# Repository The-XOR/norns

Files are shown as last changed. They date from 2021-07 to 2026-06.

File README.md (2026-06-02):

# Trapanaorecchie
Versione vergognosa e barbona dello stilosissimo monome norns.

Funzionante e compatibile al 100%, con vere porte MIDI e un uscita cuffia che non esitiamo a definire "molto utile".

L'aspetto l'e' quel che l'e', ma fatto com'e' con tutti pezzi di recupero, di piu' non si poteva fare.

## quick reference

```
git clone https://github.com/The-XOR/norns.git
cd norns
git submodule update --init --recursive
./waf configure --release
./waf build --release
```

(NB: the `--release` flag creates builds specifically for armv8/cortex-a53 instruction set, meaning optimized for rpi3 and compatible with rpi4. It also enables aggressive compiler optimizations. Omit flag if you need debug symbols or to build for a different architecture. It does need to supplied to both configuration and build steps.)

## documentation
- [user docs](https://monome.org/docs/norns)
- [API docs](https://monome.org/docs/norns/api)
- [building and execution](readme-setup.md)
- [discussion and help](https://llllllll.co)

## related
### supporting repositories
- [maiden](https://github.com/The-XOR/maiden/) | editing interface
- [softcut](https://github.com/monome/softcut-lib) | sample-cutting editor part of `matron`

### tools
- [norns disk image](https://github.com/The-XOR/norns-image) | raspbian-based disk image
- [monome linux kernel](https://github.com/monome/linux/) | custom, monome-flavored linux kernel
- [DIY shield instructions](https://github.com/monome/norns-shield) | the DIY open-source hardware variant

## acknowledgments

`matron` (control system) and `crone` (audio system) were created by [@catfact](https://github.com/catfact). `maiden` (editor) was created by [@ngwese](https://github.com/ngwese). Each grew with contributions from [@artfwo](https://github.com/artfwo), [@antonhornquist](https://github.com/antonhornquist), [@simonvanderveldt](https://github.com/simonvanderveldt),[@ranch-verdin](https://github.com/ranch-verdin), [@pq](https://github.com/pq), [@markwheeler](https://github.com/markwheeler), [@csboling](https://github.com/csboling) and many others.

norns was initiated by [@tehn](https://github.com/tehn) (monome).

## la fotogalleria...

... che lo mostra in tutto il suo splendore. Il colore e' quello pentecostale, a ricordare le ristrettezze economiche che hanno dato i natali.

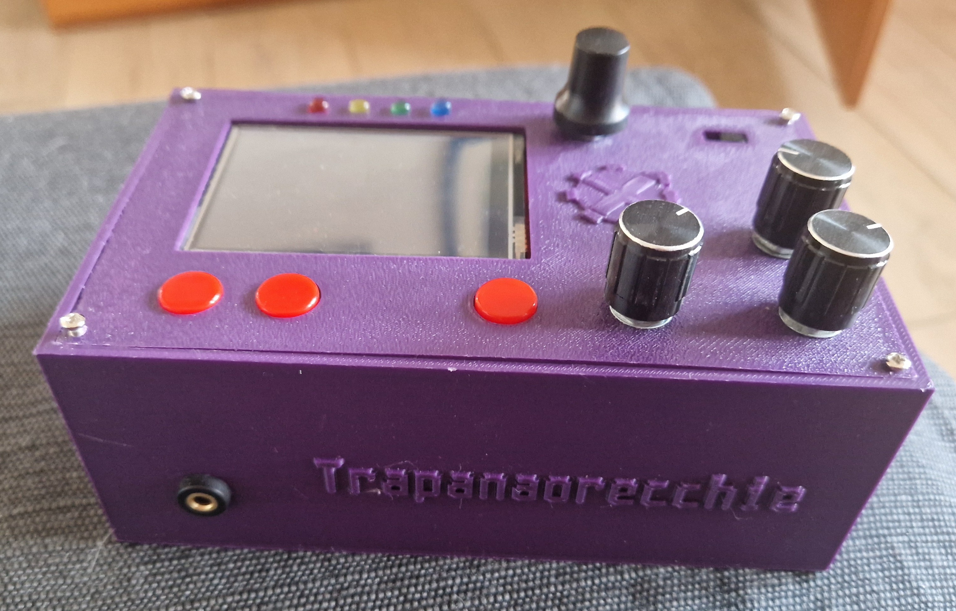
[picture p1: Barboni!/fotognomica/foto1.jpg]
e uno


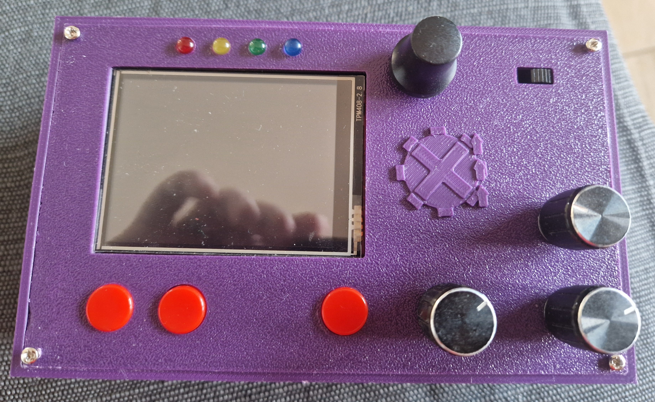
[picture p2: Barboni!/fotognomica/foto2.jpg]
e due


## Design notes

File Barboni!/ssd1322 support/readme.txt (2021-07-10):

/home/pi/linux/drivers/staging/fbtft:
1. KCONFIG: inserire il contenuto del file kconfig.merge
2. copiare in questa directory il file fb_ssd1322.c

menuconfig (kernel build):
[D]evice Drivers --> [S]taging Drivers --> [S]upport for small TFT LCD display modules -->
<M> SSD1322 driver

File makefile:
aggiungere
obj-$(CONFIG_FB_TFT_SSD1322)     += fb_ssd1322.o

file modules.order:
aggiungere
drivers/staging/fbtft/fb_ssd1322.ko

ricompilare lo kernel

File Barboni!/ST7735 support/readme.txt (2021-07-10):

Basandosi sul file "dts list", il display ST7735r viene attivato col comando:

dtoverlay=adafruit18,reset_pin=6,dc_pin=5,rotate=270

NOTA:
il piedino DC corrisponde a RS nel pdf allegato.
L'utilizzo del termine "PIN" è improprio, in realtà è il numero di GPIO.

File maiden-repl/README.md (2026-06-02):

maiden-repl
===========

the `maiden-repl` command is a terminal based alternative to the `matron`
and `supercollider` (sc/crone) REPLs provided in the web based `maiden` editor. this
command can be used independently of, or concurrently with, the web based editor. any
REPL output will appear in all connected sessions but REPL input commands and command
history.

usage
-----

`maiden-repl <matron_socket> <crone_socket>`

the default values for `matron_socket` and `crone_socket` are
`ws://localhost:5555/` and `ws://localhost:5556/` respectively which are
appropriate if `maiden-repl` is being run directly on `norns` (via ssh or serial
connection).

if running `maiden-repl` from another host insert the appropriate host name (or
IP address) for
your device such as:

```
maiden-repl ws://norns.local:5555 ws://norns.local:5556
```

building
--------

`maiden-repl` is known to build on:
* monome norns, norns shield os images
* linux (debian buster)
* macOS (13.1 Ventura)

when building directly on a norns device `maiden-repl` should be built by
default as part of the `waf` based build system for the full norns software
stack (matron, crone, etc.)

when building on linux or macOS the a secondary `cmake` based build sytem allows
for building the command independently of the full norns stack. the `cmake`
system is very rudimentary.

on linux manually install the following dependencies:
```
sudo apt-get install cmake libncursesw5-dev libreadline-dev libnanomsg-dev
```

on macOS ensure the XCode developer commandline tools are installed then manually install the following (via Homebrew):
```
brew install cmake readline nanomsg
```

from there on either linux or macOS:
```
git clone https://github.com/The-XOR/norns.git
cd norns/maiden-repl
mkdir build
cd build
cmake ..
make
```

the resulting `maiden-repl` command in the build directory can be copied out and
placed in a directory which is on one's `PATH`.

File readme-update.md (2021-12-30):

# norns update procedure

## update information and bundling

upon entering the `SYSTEM > UPDATE` menu the update folder `~/update/` is scanned for files
matching the `norns*.tgz` pattern. any attached USB disk has its root folder checked as well.
if present the following process happens:

- file is extracted
- md5 check
- if success, extract data to folder
- cleanup (delete archives and md5)

updates are stored as folders.\*

when an update is "executed" via the menu, the application runs `update.sh`
within the selected update's folder and then updates `version.txt` which is
also stored in `~/update`.

\* there is no reason to keep the update folders, they should be deleted after being run. also, an
update's version number should be checked against the current version, to prevent backwards
updating (which would likely only break a bunch of functionality).

## anatomy of an update .tgz

update versions tracked by date YYMMDD.

ie `norns180401.tgz`

inside this archive is:

`180401.tgz`
`180401.md5`

the md5 validates the tgz. if passed, `180401.tgz` is extracted to `180401/`.

inside `180401/` is `update.sh`, `version.txt`, and the payload.

`update.sh` copies included files to the correct locations (and does whatever
else needs to be done).

`version.txt` simply contains the version (ie `180401`) and is copied to `~/update`
(which is later read by matron).

files relevant to matron, crone, or maiden should be kept in respective
subfolders in the archive.

## preparation of an update

generating an update is straightforward. make a YYMMDD folder, put all the
files in there with a correct `update.sh`.

```
tar czvf YYMMDD.tgz YYMMDD
md5sum YYMMDD.tgz > YYMMDD.md5
tar czvf nornsYYMMDD.tgz YYMMDD.*
```

## delivery

presently update files are copied to `~/update` via the `SYSTEM > UPDATE` menu, which checks the remote github release against the current version.

it's possible to manually install an update by copying the update file to `~/update`, extracting it, and running `update.sh` directly.

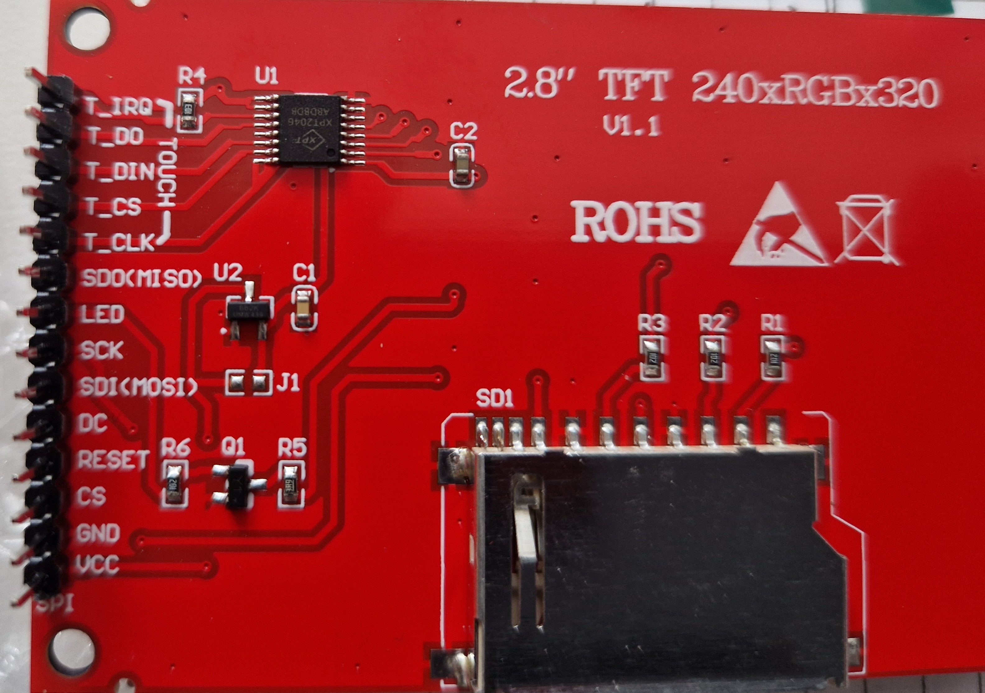
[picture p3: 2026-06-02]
Barboni!/Schema elettrificato/pinout display.jpg

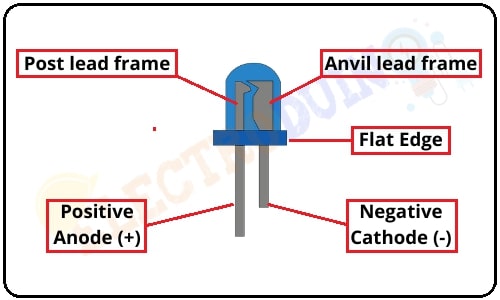
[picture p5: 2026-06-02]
Barboni!/Schema elettrificato/LED-or-Light-Emitting-Diode-Pinout.jpg

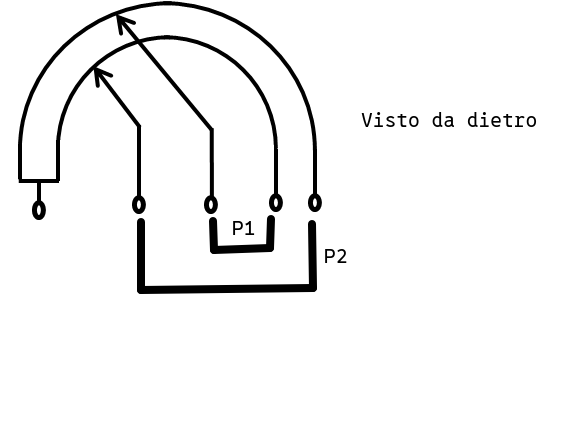
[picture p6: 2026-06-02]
Barboni!/Schema elettrificato/potenziometro a 5 pin.png

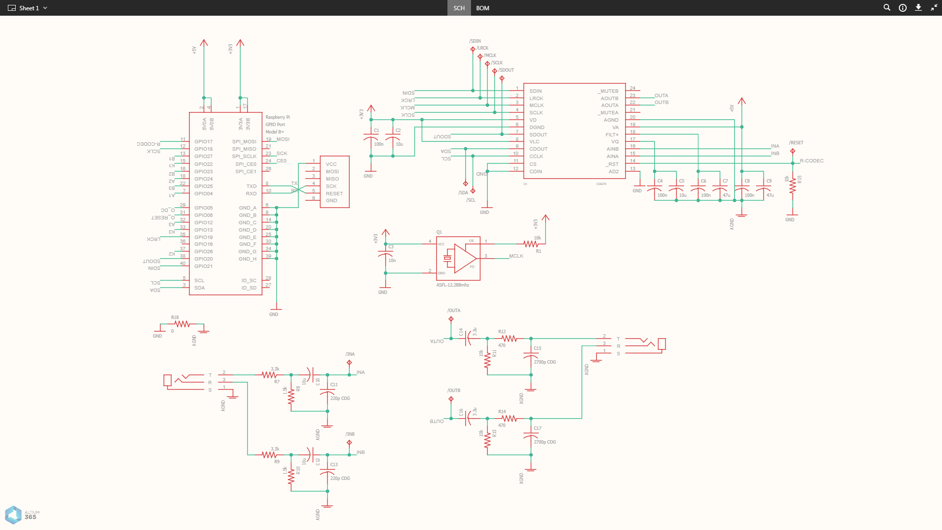
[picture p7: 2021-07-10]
Barboni!/norns-1.png

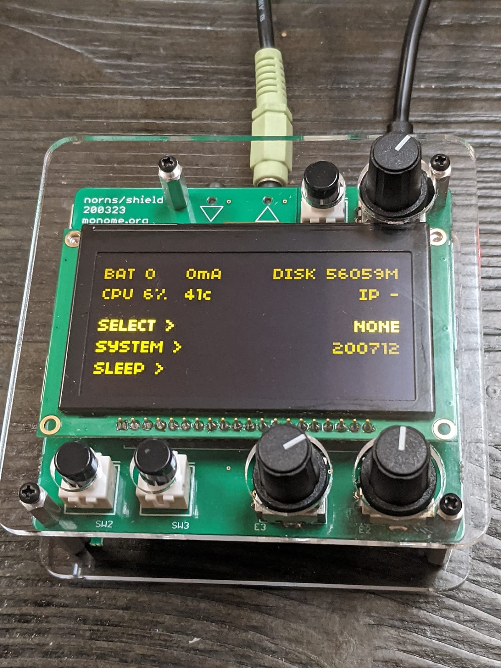
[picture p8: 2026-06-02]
Barboni!/shield.jpg

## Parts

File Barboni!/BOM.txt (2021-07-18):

Materiali da barbone utilizzati:

LCD: 
Waveshare 2.8 pollici LCD Touch Display Modulo per Raspberry Pi Pico, 2.8" LCD SPI IPS Schermo Tattile 
320×240, 262K Colori Display, Controller Touch Resistivo XPT2046, Driver ST7789

Amazon: https://www.amazon.it/gp/product/B094N94PN2/ref=ppx_yo_dt_b_asin_title_o02_s00?ie=UTF8&psc=1

Encoders:
Hikig KY-040 - Modulo encoder rotativo con 15 × 16,5 mm, con tappo a manopola per Arduino (confezione da 5) HKT1062

Amazon: https://www.amazon.it/gp/product/B07D356LRH/ref=ppx_yo_dt_b_asin_title_o04_s00?ie=UTF8&psc=1

Audio:
Behringer UCA222
(Va bene qualsiasi scheda audio con supporto ALSA, al massimo ci sarà da modificare asound.rc)

Raspberry PI3

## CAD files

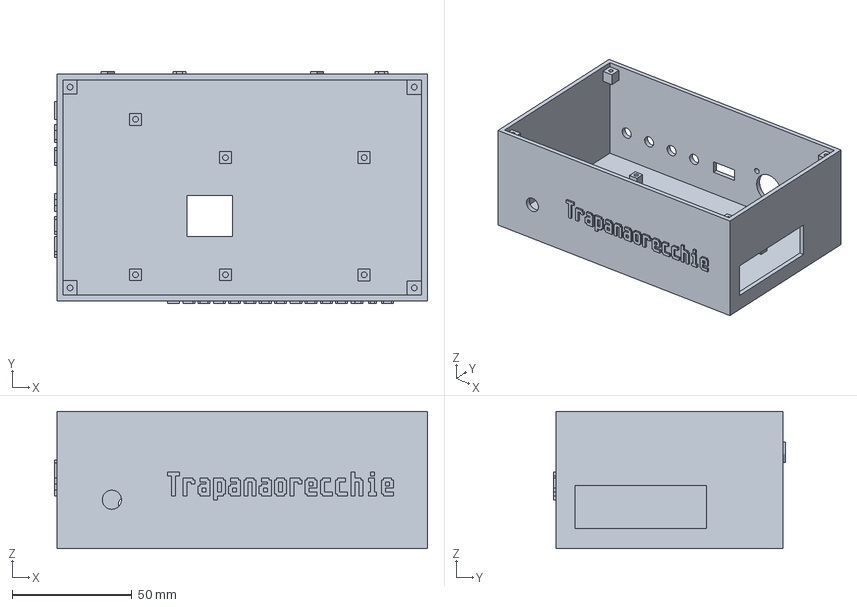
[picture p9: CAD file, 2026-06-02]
Barboni!/scatolame/Norns-Lo Scatolo.3mf
156.0 x 97.0 x 57.5 mm

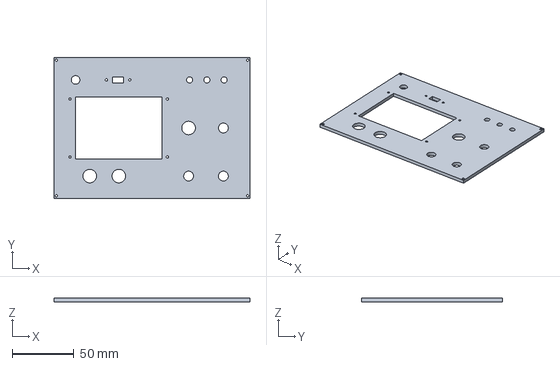
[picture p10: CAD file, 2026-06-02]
scatulun.FCStd
159.0 x 114.0 x 3.00 mm

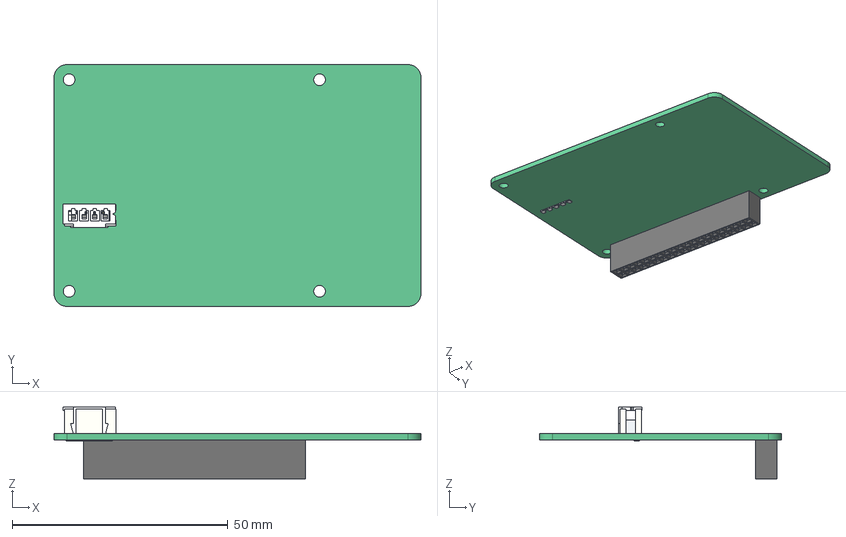
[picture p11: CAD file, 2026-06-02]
Barboni!/scatolame/daughterboard.step
85.0 x 56.0 x 16.7 mm
4 Way 2mm Pitch JST Connector - Female
B4B-PH-SM4-TB
40 pin connector header smt v3
PCB

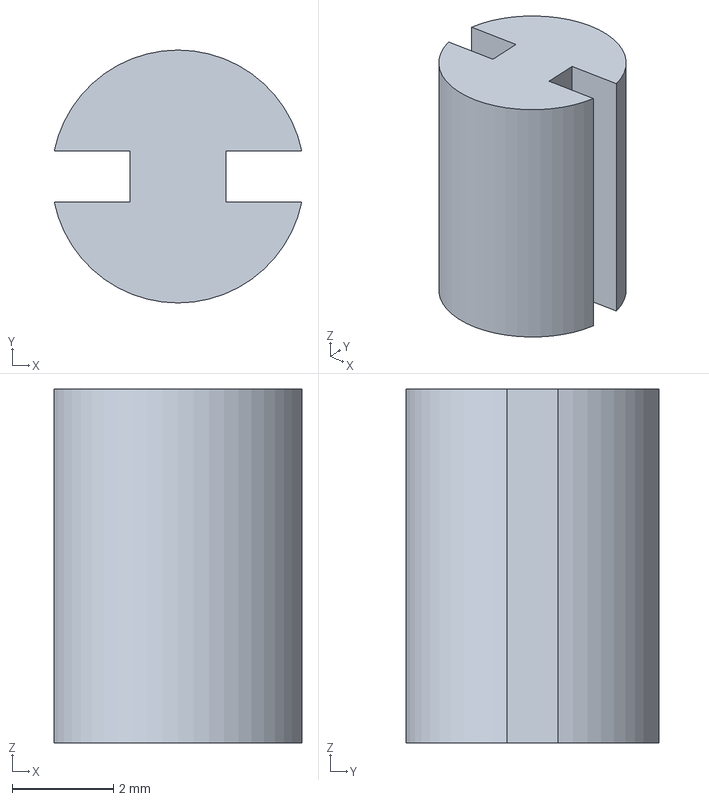
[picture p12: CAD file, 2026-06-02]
Barboni!/scatolame/Rialzo led.FCStd
4.90 x 5.00 x 7.00 mm

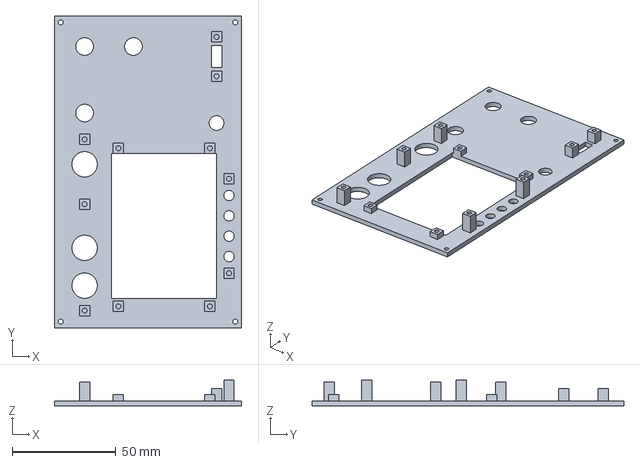
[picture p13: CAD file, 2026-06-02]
Barboni!/scatolame/Norns-Pannello frontaliero.3mf
90.0 x 150.0 x 12.5 mm

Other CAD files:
Barboni!/scatolame/norns board.FCStd
Barboni!/scatolame/Norns.FCStd

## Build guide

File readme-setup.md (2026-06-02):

# norns setup

## build prerequisites
norns/matron/src/args.c : Impostare il famebuffer da usare
### standard packages

these can be installed from the default Debian repositories: 

```
sudo apt-get install libevdev-dev liblo-dev libudev-dev libcairo2-dev liblua5.3-dev libavahi-compat-libdnssd-dev libasound2-dev libncurses5-dev libncursesw5-dev libsndfile1-dev libjack-dev libnanomsg-dev
```

### other packages / sources

on norns / raspberry pi, the following should be installed from monome's repositories:

```
curl https://keybase.io/artfwo/pgp_keys.asc | sudo apt-key add -
echo "deb https://package.monome.org/ stretch main" | sudo tee /etc/apt/sources.list.d/norns.list
sudo apt update
sudo apt install libmonome-dev libnanomsg-dev supercollider-language supercollider-server supercollider-dev
```

for other platforms (x86, amd64), these packages can again use the standard repositories:

```
sudo apt install libnanomsg-dev supercollider-language supercollider-server supercollider-dev
```

and `libmonome` must be built and installed from source:

- clone, build, and install:
```
git clone https://github.com/monome/libmonome
cd libmonome
./waf configure && ./waf && sudo ./waf install
```

- add `/usr/local/lib` to library search paths. the recommended way to do this is by editing `/etc/ld.so.conf`. (use of the `LD_LIBRARY_PATH` variable is deprecated, since it willl override binary-specific settings.)

### desktop

using the `desktop` build option has additional requirements:
```
sudo apt install libsdl2-dev
```

## building norns

```
git clone https://github.com/The-XOR/norns.git
cd norns
git submodule update --init --recursive
./waf configure
./waf
```

this should build several executables under `norns/build/<name>/`:

- `matron`: the main norns system application: runs scripts, interfaces with controllers and screens
- `crone`: the norns "audio backend," a JACK application which routes audio, runs the `softcut` buffer processing system, and hosts built-in effects
- `ws-wrapper`: utility which wraps the standard I/O of a process in websockets; used to expose `matron` and `sclang` to the web IDE
- `watcher`: watchdog utility
- `maiden-repl`: command-line interface to `matron` and `sclang` REPLs

(note that the `maiden` webserver/IDE is managed separately, in its own repository.)

### supercollider 
norns also uses some custom supercollider classes. thess files must be copied to the default location for user SC extensions; we provide a script to do so:

```
pushd sc
./install.sh
popd
```

### desktop

for building on desktop, add the `--desktop` option to both `waf` steps (configure and build):

```
./waf configure --desktop
./waf build --desktop
```

(NB: `waf` assumes `build` as the default command, which is why we can omit it above.)

## launching components

in normal use, the component executables should be managed by `systemd` services, which take care of websocket wrapping.

for development, it is often useful to run component processes manually from an `ssh` session. this is best accomplished using three different sessions (`screen` is an option), each launching the following in this order:

- 0. first, ensure that JACK is running: `systemctl start norns-jack`
- 1. `norns/build/crone/crone` - runs the norns audio backend; prints some status stuff, but is not interactive
- 2. `sclang` - runs supercollider, spawns a `scynth` instance which is then routed through `crone`; provides a nice REPL
- 3. `norns/build/matron/matron` - runs the main norns system; provides a very basic REPL (no readline)

in general, changes to `matron` sources require only building and relaunching `matron`, changes to supercollider classes require relaunching `sclang`+`matron`, and changes to `crone` sources require relaunching all three.

## launching `maiden` (web UI client)

get most [recent version](https://github.com/monome/maiden/releases)

download to `~/maiden/` and untar

execute with `./maiden.arm -debug -site ./app/build -data ~/norns/lua/`

## launching on desktop / other platforms:

when running norns on desktop computers or custom hardware platforms, you will want to provide `matron` with appropriate runtime configuration options using the `matronrc.lua` file. this should be copied to the user's home directory and customized there. see the comments in that file.

## docs

if you want to generate the docs (using ldoc) first install:

```
sudo apt-get install luarocks liblua5.1-dev
sudo luarocks install ldoc
```

to generate the docs:

```
ldoc .
```
in the root norns folder. it should run without errors or warnings.

to read the documentation, point the browser window with Maiden loaded to [http://norns.local/doc](http://norns.local/doc) (or use IP address if this doesn't work).

to install the documentation in [the docs website](https://monome.org/docs/) please copy it over manually to [the site's repo](https://github.com/monome/docs/).

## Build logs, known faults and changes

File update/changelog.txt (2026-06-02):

# 240911

# norns 2.8.4

- NEW norns font with 86 new glyphs #1783 @dstroud
- FIX paramset fixes #1787 #1796 @dstroud
- FIX binary params #1781 #1785 @dndrks
- FIX keyboard wakes up screen #1778 @hallmar

# 240424

# norns 2.8.3

- NEW acceleration for inf pots #1776 @tehn
- FIX grid rotation #1772 @tehn
- FIX tape play return on open #1770 @catfact
- FIX update.sh apply shield update correctly

# 240221

# norns 2.8.2

- NEW support for i2c adc inf pots, as encoders @tehn
- NEW particle font @dansimco
- NEW hotswap lib (from crow) @trentgill
- NEW midi clock in port selection @catfact
- FIX remove system/log @tehn
- FIX link start/stop @artfwo

# norns-image

- FIX disable logging @catfact

# 231114

# norns 2.8.1

- NEW screen overhaul, allowing higher frame rate and various improvements
#1720 @tlubke @catfact @Dewb
- NEW wall time measurement #1719 @catfact
- NEW screen.sleep #1727 @ambv
- FIX oneway midi devices #1595 @catfact
- FIX softcut phase inversion #1725 @catfact

# 231023

# norns 2.7.9

- NEW cpu_time measurement #1718 @catfact
- NEW mod system additional hooks #1716 @sixolet
- NEW lib reflection #1713 @ryleelyman
- FIX lfo offset behavior #1715 @sonocircuit

# 231011

# norns 2.7.8

- NEW lfo lib v2 #1692 @dndrks
- FIX tape preview debounce #1703 @ryleelyman
- FIX systemcmd buffer size #1707 @catfact
- FIX char safety #1705 @tehn
- FIX file select listing optimization #1705 @tehn
- FIX file select listing optimization #1712 @beels
- FIX dev_monitor messages more informative #1710 @ambv
- FIX util.wrap global var correction #1704 @sixolet
- FIX restart tuning #1695 @dndrks
- FIX midi mapping tuning #1696 @dndrks
- FIX softcut voice sync parameter order #1677 @catfact
- FIX menu disk display allow large numbers #1690 @radishmouse
- FIX musicutil 7th chord scale generation #1688 @Dewb

# image

- FIX disble hciuart #1700 @tehn

# 230614

# norns 2.7.7

- FIX fileselect bug #1681 @dndrks

# 230526

# norns 2.7.6

- NEW fileselect filters #1678 @dndrks
- FIX midi clock #1680 @dndrks

# 230509

# norns 2.7.5

- FIX screen.export_png reverted, screen.export_screenshot added @tehn
- FIX battery menu fix @dndrks

# 230405

# norns 2.7.4

- NEW png export with scaling and frame #1669 @tehn
- NEW system settings menu, battery warning #1668 @tehn
- NEW char/key conversion #1659 @niksilver
- NEW crow v4 features #1662 @trentgill
- NEW allow midi send to all channels #1642 @zjb-s
- NEW user gamepad profiles #1671 @p3r7
- FIX gamepad support #1624 @p3r7
- FIX lfo lib improvements #1630 @dndrks
- FIX various minor fixes (much appreciated)

# 221214

# norns 2.7.3

- NEW preview for tape select #1607 @ryleelyman
- NEW function to check norns version on script load #1613 @ryleelyman
- NEW keyboard menu key update #1611 @schollz
- NEW lattice v2 #1616 @ryleelyman
- FIX param accum mapping, accept wider range of inputs #1606 @zjb-s
- FIX tempo update bug with link #1617 @dndrks
- FIX menu key management #1619 #1620 @p3r7
- FIX lfo lib use lattice v2 #1626 @dndrks
- FIX wifi pw entry #1627 @dndrks

# image

- fix logrotate

# 220802

# norns 2.7.2

- FIX midi remove callback #1590 @catfact
- NEW lfo library #1591 @dndrks
- FIX lattice downbeat placement #1587 @sixolet
- NEW menu-based password change also applies to SMB and hotspot #1570 @dndrks
- FIX param group and separator initializers #1584 @dndrks
- NEW action for tempo change #1575 @dndrks
- FIX param separators in lookup table #1539 @dndrks
- FIX link C API #1572 @artfwo
- FIX screen_display_image_region registration @ngwese
- FIX softcut remove unused filter command #1558 @catfact
- NEW pset delete, pset number on action #1544 @dndrks

# 220321

# norns 2.7.1

- FIX softcut initialization glitch @catfact
- FIX compilation optimization flags @catfact
- NEW system log export @tehn
- FIX polysub/polysub memleaks @catfact

# maiden 1.1.6

- FIX content type so .sc files can be edited in maiden once again (#219)
@ngwese
- FIX address linting errors (#216) @midouest

# image

- update journalctl service @tehn
- update jack service to properly select codec @ngwese

# 220306

included on image 220306

# norns 2.7.0

- NEW image surfaces for drawing, png loading, and reuse @ngwese
- NEW core engines now included @tehn @catfact
- FIX remove boost dep @catfact
- NEW jack load monitor, xrun report @catfact
- FIX tape index from file system, not index.txt @stvnrlly
- NEW pset delete confirm @nattog
- FIX param collision warning instead of error @catfact

# 220129

# norns 2.6.1

- FIX intonation lib, make lamonte monotonic @catfact
- NEW numerous improvements for desktop compilation @winder
- NEW tabutil lib, add select_values @nattog
- FIX softcut optimizations @catfact
- FIX pset writing order @catfact
- FIX mods, handle no matching @ngwese
- FIX build options for desktop @catfact
- NEW tabutil lib, add gather @ryanlaws
- FIX ensure favorites exist prior to load @tyleretters
- NEW password entry within SYSTEM menu @tehn
- NEW watcher pw reset touch /boot/norns.txt @tehn
- FIX verbose missing engine message @dndrks
- NEW script rerun shortcut norns.rerun() @tyleretters
- NEW lattice lib pattern delay @schollz
- NEW sequinz lib peek @tyleretters
- FIX screen message for jack fail @tehn
- NEW musicutil roman numeral chord generation @dewb
- FIX link adopt tempo when joining @dewb
- NEW clock param to enable/disable link start/stop sync @dewb
- NEW system update download progress @tehn
- NEW tilt support for grids @okyeron
- FIX screen png-display @tehn
- FIX lattice lib patterns pulse in order based on id @schollz
- NEW link transport activation from norns @schollz
- FIX crow clock consistency @sixolet
- FIX param name collision @dndrks
- NEW CPU profiling tools @catfact

# maiden 1.1.5

- NEW full light / dark theme @dansimco
- FIX various styling improvements and increased contrast

# image

- NEW update libmonome, improves grid stability @trentgill

# 210927

# norns 2.6.0

- NEW hooks and mods system @ngwese @catfact
- NEW custom events, c bindings @ngwese
- NEW sequins library @tyleretters @trentgill
- NEW softcut non-real-time functions @ryleelyman
- NEW keyboard layouts @p3r7
- NEW hold K1 in SELECT to fast-scroll @dndrks
- FIX util.wrap and util.wrap_max bounds @dndrks
- FIX tab.count @discohead
- FIX crash when detecting crow @nihilazo
- FIX numerous docker-related fixes @winder
- FIX cleanup behavior with clean/load script @ngwese
- FIX support PSETs above 99 @p3r7
- NEW sky: add polyperc/polysub param def @ngwese
- NEW textentry: add keyboard support @p3r7
- NEW keyboard layouts menu selection @p3r7
- FIX softcut phase inversion @catfact

# maiden 1.1.4

- NEW preview audio files on device in browser @stvnrlly
- FIX explicit (instead of implicit) untitled script creation on initial landing view
- NEW loading animation when loading scripts/audio into editor
- NEW add version metadata to maiden cli @winder
- NEW allow release builds for any architecture @winder

# 210706

# norns 2.5.4

- FIX clock sleep interlaced with sync @artfwo
- FIX crow init @trentgill

# 210701

## maiden 1.1.2

- NEW add ctl+enter (or cmd+enter) key binding to trigger editor selection evaluation @schollz
- NEW select current editor line for evaluation if no selection exists @schollz
- FIX disable auto correction/completion/capitalization in the REPL  @xmacex

# 210630

## norns 2.5.2

- NEW crow 3 support and simplified namespace @trentgill
- NEW util.file_size @dndrks
- FIX clock offsets @artfwo
- FIX device monitor @catfact
- FIX crow clock out @tehn

# 210607

## norns 2.5.1

- NEW latest grid support (CDC) @catfact
- FIX non-crow CDC devices not sent crow queries @tehn
- FIX menu update bug due to jack change @tehn
- FIX menu redraw bug @schollz

# 210524

## norns 2.5.0

- NEW clock: overhauled clock system, uses jack time and improved sync @artfwo
- NEW softcut: query position feature @catfact @tehn

# 210411

## norns 2.4.11

- ADD menu: SYSTEM > RESTART (like reset, but don't erase state) @tehn
- FIX softcut: set loop points and position at same time @catfact
- FIX fileselect: allow symlinks (ie, to support usb disks) @csboling
- FIX screenshot: antialias mode to GRAY to prevent color distortion @csboling
- ADD params: get_range() to control type @justmat
- ADD lattice: hard reset with modified divisions @kasperbauer

## maiden 1.1.1

- ADD documentation link for catalog entries @ngwese
- ADD improved UX with installing/updating scripts @ngwese
- FIX supercollider repl eval @ngwese

# 210323

## norns 2.4.10

- NEW cpu monitoring shows all four cores, UI adjustment @tehn
- NEW lattice: add hard reset @schollz
- FIX crow: multiline packet parsing @trentgill
- FIX params: exclude trigger type from params.bang @andr-ew
- FIX compilation: osc handler signatures @catfact

# 210301

## norns 2.4.9

- NEW update: use releases.txt and provide beta option @tehn
- NEW osc key/enc: add single arg version ie /remote/enc/n d @catfact
- NEW crow update 2.1.2 @trent
- NEW hide crow subfolder inside scripts @tehn
- ADD param: taper get_range @justmat
- ADD menu: _menu.params_rebuild() for dynamic menus @schollz
- FIX softcut init values @catfact
- FIX font list in docs @hiqualityh2o
- FIX sane param defaults @tehn

# 210114

## norns 2.4.8

- NEW keyboard: easier keyboard management in scripts @tehn
- NEW keyboard: basic menu control via keyboard @tehn
- FIX params: reverb/comp settings persist between script loads
- NEW help system: quick script reference via REPL @tehn
- NEW lib: lattice is a clock patterning framework @tyleretters
- NEW api: norns.shutdown() can be called by script @tyleretters
- FIX clock: tune sync multiplier thresholds @artfwo
- FIX screen: clamp level input, prevent crash @tehn
- NEW lib: util.wrap() util.wrap_max() @tyleretters
- NEW params: read() accepts and passes "silent" arg @schollz
- NEW menu: now 16 vports for midi @dndrks
- NEW params: pmap now autosaves @dndrks
- GONE norns.fetch: use ;install in maiden instead @tehn

## maiden

- NEW ;install command for fetching remote repositories
- NEW refresh all button @ngwese
- NEW script stop/clear button @ngwese
- FIX improve implicit untitled.lua creation @ngwese
- FIX upgrade versions @ngwese
- CHANGE rename sc -> supercollider for clarity @ngwese

## norns-image

- NEW watcher: separate application for key-trigger restart @tehn

# 201202

## norns 2.4.7

- NEW norns.fetch() for downloading git urls to dust @tehn
- NEW screen: peek/poke @csboling
- NEW screen: rotate/translate/save/restore/text_rotate @tyleretters
- NEW screen: blend modes @tlubke
- NEW util: radian-degree convresions @tyleretters
- NEW hid: keyboard detection @catfact
- NEW platform: detect norns/shield/other hardware, improve messages @tehn
- FIX params: mapping control full ranges @synthetiv

# 201115

## norns 2.4.6

- CHANGE increase default encoder sensitivity for playmode @tehn
- FIX menu lock bugs @tehn
- FIX util.round_up @ryanlaws

# 201113

## norns 2.4.5

- NEW levels: allow +6db, show unity on mix menu @tehn
- NEW params: remember last used pset @tehn
- NEW params: enable mapping of binary types @schollz
- FIX softcut: don't clamp record offset @catfact
- FIX menu: playmode lock bug @tehn
- FIX engine: deinit cleanup @tehn @catfact
- FIX musicutil: revert rendering of sharps @tehn
- FIX tape: create dir if user deleted it @catfact

# 201029

## norns 2.4.4

- FIX midi/crow listing bug @ngwese

# 201023

## norns 2.4.3

- NEW softcut: copy buffers with reverse and crossfade @csboling
- NEW softcut: grab buffer data (for visualization) @csboling
- NEW softcut: crossfade and preserve buffer options for buffer_clear @csboling
- NEW script favorites @zzsnzmn
- NEW virtual raw midi port support @ngwese @patriciogonzalezvivo
- NEW midi sysex support improved @ngwese
- NEW params: type binary for trig, toggle, momentary @andr-ew
- NEW params: option to disable mapping @ngwese
- NEW deque: add peek, peek_back, find @ngwese
- NEW sky: additions and refinements @ngwese
- NEW ui slider direction option @ericmoderbacher
- FIX midi: handle running status @ngwese
- FIX musicutil: scale refinement @markwheeler
- FIX softcut: clamp params @catfact
- FIX update system: clean up @tridae
- FIX er: handle empty table, add shift @catfact
- FIX build: remove boost, use moodycamel @catfact
- FIX prevent crash when trimming unicode strings @markwheeler
- FIX tape: protect from overwriting files @csboling
- FIX script preview: remove trailing whitespace @csboling
- FIX git housekeeping @ngwese
- FIX param menu: restore fine control after fileselect @tomwaters
- FIX controlspec: quantum not set when copying @tomwaters

## image

- NEW kernel 4.19.127-16 @ngwese

## norns 2.4.2

- NEW crow 2.0 support @trentgill
- NEW libs: deque, observable, weaktable, watchtable, defaulttable @ngwese
- NEW fileselect up-folder entry @csboling
- NEW file param E3 now scrolls files in folder @csboling
- NEW fileselect resume folder location @csboling
- NEW controlspec quantum and wrap @csboling
- NEW number param wrap @csboling
- NEW luaunit @ngwese
- FIX sndfile memleak @catfact
- FIX crow send overflow @csboling

## image

- NEW 'maiden' alias

# 200604

## norns 2.4.1

- NEW paths table @ngwese @tehn
- NEW patterntime lib overdub feature @dndrks @tehn
- FIX softcut level is pre-aux send @catfact
- FIX clock performance @artfwo
- FIX crow lib cleanup @trentgill
- FIX param hiding within groups @tlubke
- FIX filter lib @catfact
- FIX crow.connected status @csboling

# 200424

## norns 2.4.0

- NEW clock system! @artfwo
- NEW clock support for crow in/out
- NEW OSC remote for key/enc
- FIX pset naming and save cancel
- FIX crow reset behavior @trentgill
- FIX various minor issues, see github

# 200328

## norns 2.3.1

- NEW (BETA) link support @artfwo
- NEW lua filters lib @catfact
- FIX mix levels and rev/comp state don't save in psets, persist in system.state
- FIX param hide/show
- FIX update docs

# 200323

## norns 2.3.0

- NEW parameter menu system, many new features
- NEW tape naming on record, indexing
- NEW soft reset by 10sec hold K3-K2-K1 sequentially
- NEW tape play now loops, supports mono files @widdly
- FIX remove ws logging, rescue disk space @ngwese
- FIX softcut buffer write and clear, meters @catfact
- FIX more effective reset, remove configs

# 200218

## norns 2.2.9

- FIX system reset is more thoroguh (resets levels and vports)
- NEW softcut as submodule @catfact
- FIX integrate maiden-repl @ngwese
- FIX softcut buffer read skipped remainder frames @catfact
- FIX expose screen.text_extents @antonhornquist
- FIX extract _norns.reset @pq

# 200129

## norns 2.2.8

- FIX USB device managment crashes (!) @ngwese
- FIX softcut buffer management @catfact
- FIX softcut defaults and docs @catfact
- FIX engine deinint @antonhornquist
- NEW audio i/o reverse mechanism for shield
- NEW clear script hotkey (K1+SELECT)

# 200121

## norns 2.2.7

- NEW crow 1.0.3 syntax update @trentgill
- NEW crow asl markup @pq
- NEW CLI maiden revived @ngwese
- NEW force update by holding K1 when selecting SYSTEM > UPDATE

## maiden 1.0.1

- NEW update all @jlmitch5 @ngwese
- NEW project listing indicates installed or not @jlmitch5 @ngwese

# 200106

## norns 2.2.6

- NEW fileselect shows audio file lengths @markeats

# image

- FIX samba config

# 191230

## norns 2.2.5

- NEW softcut buffer disk worker thread @catfact
- FIX overhaul API docs @scazan
- FIX reset encoder sens/accel on script reset

## image

- NEW kernel update, adds powermate support, shield wifi
- NEW samba file server
- FIX clean up logs, remove rsyslog
- XXX webdav

# 191201

## norns 2.2.4

- FIX vu meters hugely improved @catfact
- FIX clear screen before entering play mode
- FIX several small typos that broke big things

# 191126

## norns 2.2.3

- NEW scripts can set encoder sensititivty and accel
- NEW monome grid device intensity
- ADD crow.add and crow.remove user callbacks @audionerd
- FIX missing engine error message reporting
- FIX wif menu indication
- FIX system update indication improvements
- FIX system globals, menu code organization

## image

- NEW webdav file server

# 191028

## maiden 1.0.0

- NEW install, update, and remove projects based on a catalog of known scripts from with maiden (web) or maiden cli (ssh) @ngwese
- NEW directly open existing files within the editor via URLs @ryanlaws
- NEW refined, flatter file browser look @ngwese
- NEW allow editing of json files @ngwese
- FIX protect code, data, and audio folders from accidental deletion
- FIX populate file rename dialog with current file name by default @synthetiv
- FIX fix blank screen, scrollTo errors with using MS Edge @synthetiv
- FIX ensure CTRL+P (CMD+P) plays the current script @ryanlaws
- FIX maintain REPL size with resizing the browser window @synthetiv
- FIX more distinct highlighting on REPL tabs @synthetiv

## norns 2.2.2

- FIX syscmd memory leak @catfact
- ADD crow connected function @pq
- ADD crow output systax udpate @trentgill
- FIX global reset after cleanup @antonhornquist
- FIX clock overflow prevention @Dewb
- ADD new font glyphs @Dewb
- ADD script defined crow.add and crow.remove @audionerd

# 191016

## norns 2.2.1

- FIX multi-device midi @ryanlaws
- FIX crow detection
- FIX select menu doesn't stall lua scheduler
- FIX tape audio clipping wrap @catfact
- FIX clock details @artfwo @Dewb
- FIX crow reset function @pq
- FIX globals cleanup @pq
- ADD crow user receive function
- ADD new glyphs in default font @Dewb

# 190930

## norns 2.2.0

- NEW crow support
- FIX vu polls now use dbfs scaling @catfact
- FIX (BREAKING) audio.file_info() now uses absolute path
- NEW system_cmd async os call function
- NEW softcut level_slew_time slews level (not rec/pre level)
- FIX softcut level_slew_time -> recpre_slew_time
- NEW softcut pan_slew
- FIX softcut pan flip channels, scale from -1.0 (L) to 1.0 (R)
- FIX softcut level_cut_cut arg order @catfact
- FIX softcut equal power pan @catfact
- FIX softcut initialization @catfact

# 190817

## norns 2.1.1

- FIX softcut sample rate bug @catfact

# 190801

## norns 2.1.0

- NEW clocks system @artfwo
- NEW crone routings: tape->cut, tape->aux @dewb
- NEW softcut post-filters @catfact
- NEW softcut reset command @catfact
- NEW low battery screen alert
- FIX crone compressor timing @catfact
- FIX engine loading logic fix @catfact
- FIX display_png crash @okyeron
- FIX screensaver timer now reset by enc/key
- FIX wifi init @okyeron
- FIX duplicate engine error message
- FIX better error message for missing include

# 190422

## norns 2.0.1

- NEW softcut phase_offset command
- FIX polls work with no engine @catfact
- FIX softcut reset now resets more params (properly)
- FIX fileselect, empty folders display "no files" (less confusing)
- FIX engine report @catfact

# 190405

## norns 2.0.0

- NEW *** crone is now a dedicated application (previously it was supercollider): audio routing, mixing, reverb, compression, tape, and softcut (multivoice sampling engine). @catfact
- NEW * networking system overhauled. @ngwese, @simon
- NEW * menu navigation redesigned.
- NEW * user folder (dust) management redesigned to facilitate decentralized sharing.
- NEW update system via internet connection (direct from github release)
- NEW arc support @artfwo
- NEW HID support @artfwo @okyeron
- FIX revert to scsynth, no longer using supernova

- NEW more fonts added for screen drawing. @catfact
- NEW fine control in PARAM menu (hold K3 while E3) @ngwese
- FIX empty lists now say "none" instead of remaining blank
- NEW musicutil chord library @markwheeler
- NEW matron framebuffer selection via commandline @catfact
- FIX memory leaks @catfact @ranch-verdin
- NEW 'include()' helper function
- FIX now display "loading..." after loading script (waits for engine load)
- FIX system device menu aesthetics
- FIX ldoc cleaned up
- NEW screen png export
- NEW screen png import @okyeron
- NEW crone compiles on macos @catfact
- FIX overhaul device vport system @artfwo
- NEW intonation lib @catfact
- NEW 'listselect' helper class
- NEW protect engine table functions @pq

## maiden 0.13.0

- NEW single-panel sidebar for new dust layout @ngwese
- NEW help menu quicklinks @ngwese
- NEW ctrl/cmd-8 to evaluate current editor selection in REPL @ngwese
- FIX renaming files @ngwese
- FIX command line syntax @ngwese
- FIX config page is a dialog @jlmitch
- NEW ;restart ;start ;stop REPL messages to control matron remotely

## image

- NEW kernel update with further wifi support, CM3+ support
- NEW use NetworkManager
- FIX limit logging
- FIX init services

# 181101

## norns 1.1.2

- NEW cpu and temperature monitoring in SYSTEM menu
- FIX i2c cpu hit bug
- FIX tape playback
- FIX revert to light reverb algo
- ADD lockout PLAY mode if script does not define redraw()

## dust

- ADD mlr clip save to file
- ADD passthru example engine @catfact
- FIX loom optimizations @markwheeler

# 181023

## norns 1.1.1

- NEW cpu and temp monitoring in system menu
- FIX engine reset at cleanup

## image

- updated supercollider to 3.10.0 @artfwo

## dust

- NEW r engine and examples @jah
- NEW fm7 @lazzarello
- NEW tuner @markwheeler
- FIX softcut bus deinint @catfact
- FIX mlr long file loading, increase buffer size, reduce to 4 tracks

# 181008

## norns 1.1.0

- BREAKING parameter ids. args to `params:add_number()` (etc) changed
- NEW OSC mapped parameters @artfwo
- ADD updated docs @pq
- FIX fileselect unit (affects mlr,etc)

## dust

- ADD mlr update (recall feature)

# 181002

## norns 1.0.4

- BREAKING parameter ids. args to `params:add_number()` (etc) changed
- NEW `params:add{}` table-based param initializer
- NEW script-level globals reset on load @pq
- NEW cols/rows query added to grid @markwheeler @okyeron
- NEW midi key pressure, channel pressure @markwheeler
- NEW param type: trigger
- NEW audio reset, in the system menu. temporary fix for wifi-router-based timesync crashes
- FIX taper param now midi mappable @artfwo
- FIX input control on LEVELS screen now works
- FIX screen attributes now saved/restored when switching between menu/play mode
- FIX encoder sensitivity in LEVELS menu screen
- FIX battery current reading (now reads all digits)
- FIX various grid/midi bugs @markwheeler

## image

- UPDATE kernel which fixes earlier USB issues (speed restored to USB2)

## dust

- NEW molly the poly @markwheeler
- NEW loom @markwheeler
- NEW cranes @danderks
- NEW ekombi @tyler
- NEW paths @justmat
- NEW andr @martinmestres
- ADD ack overdrive and mute groups @jah
- FIX param API @artfwo
- FIX rebound midi output

# 180904

## norns 1.0.3

- FIX midi/grid management system behavior

## image

- FIX USB limited to USB1.1 to prevent kernel bug which caused grids/midi to misbehave

## dust

- NEW boingg (@declutter)

# 180828

## norns 1.0.2

- NEW now DSP is multi-core, supernova has replaced scsynth (@catfact)
- NEW midi and grid management system
- FIX SoftCut quality improvements, channel increase
- FIX -inf for levels (@antonhornquist)
- FIX vu display
- FIX screen drawing improvement (@markwheeler)

## image

- FIX monome package repo moved
- FIX prevent `apt-get update` from touching the kernel

## dust

- NEW passerby engine (@markwheeler)
- NEW rebound (@nf)
- NEW channel changer (@speakerdamage)
- UPDATE foulplay (@notjustmat, @junklight)
- UPDATE playfair
- UPDATE mlr

# 180707

## norns 1.0.1

- ADD parameter menu midi-cc assignment
- ADD screen drawing functions (@markwheeler)
- FIX screen drawing accuracy
- FIX cleaner shutdown
- FIX clean up LEVELS display, fix output VUs
- FIX hide battery warnings (harmless, need driver fix)
- FIX allow spaces in text entry (for wifi passwords, etc) (@dewb)
- FIX ws-wrapper args (@ngwese)
- FIX script cleanup (@pq)
- FIX better error catching on script load (@pq)

## maiden 0.9.4

- initial dark editor theme (@pq)
- plumbing for custom lua mode, improved syntax checking (@pq)
- norns specific lua script/code snippets (@pq)
- additional linting and cleanup for maiden code (@Jwhile)
- sending commands via the sc repl now works (@ngwese)
- initial snippet support for common matron script functions (@pq)
- improved rendering of tab characters in repl (@pq)
- button highlighting on hover (@anthonybarsotti)

## image

- FIX ws-wrapper arg order for maiden, sc ws-wrapper fix (ngwese)

## dust

- ADD Gong, Shifty, and Bob engines (@jah)
- ADD KarplusRings engine (@burn)
- ADD MusicUtil and Graph libs (@markwheeler)
- ADD BeatClock lib (@dewb)
- ADD Scripts (@jah, @burn, @mat, @ocreurer, mhetrick)
- ADD Studies 1-3 (@mhetrick)
- FIX Polyperc DC (@catfact)

# 180603

## norns 1.0.0

- ADD multi-paramset saving
- FIX audio startup refactored (@catfact)
- FIX update method now requires restart
- FIX wifi connection improvement, timeout added (@pq)

## maiden 0.9.1

- ADD enable basic lua snippet and auto complete support (@pq)
- ADD double clicking section headers within the file browser will collapse
the entire section
- CHANGE allow maiden to serve HTTP from a file descriptor (@nf)
- CHANGE directories grouped/sorted before files in the file browser
- FIX exposes `dust/lib/lua`

## image

- CHANGE start maiden on port 80
- FIX jackd service setting, add -s

## dust

- ADD PolySub, SoftCut, abstractions
- FIX move pset files into data/subfolders
- FIX er algorithm (@catfact)

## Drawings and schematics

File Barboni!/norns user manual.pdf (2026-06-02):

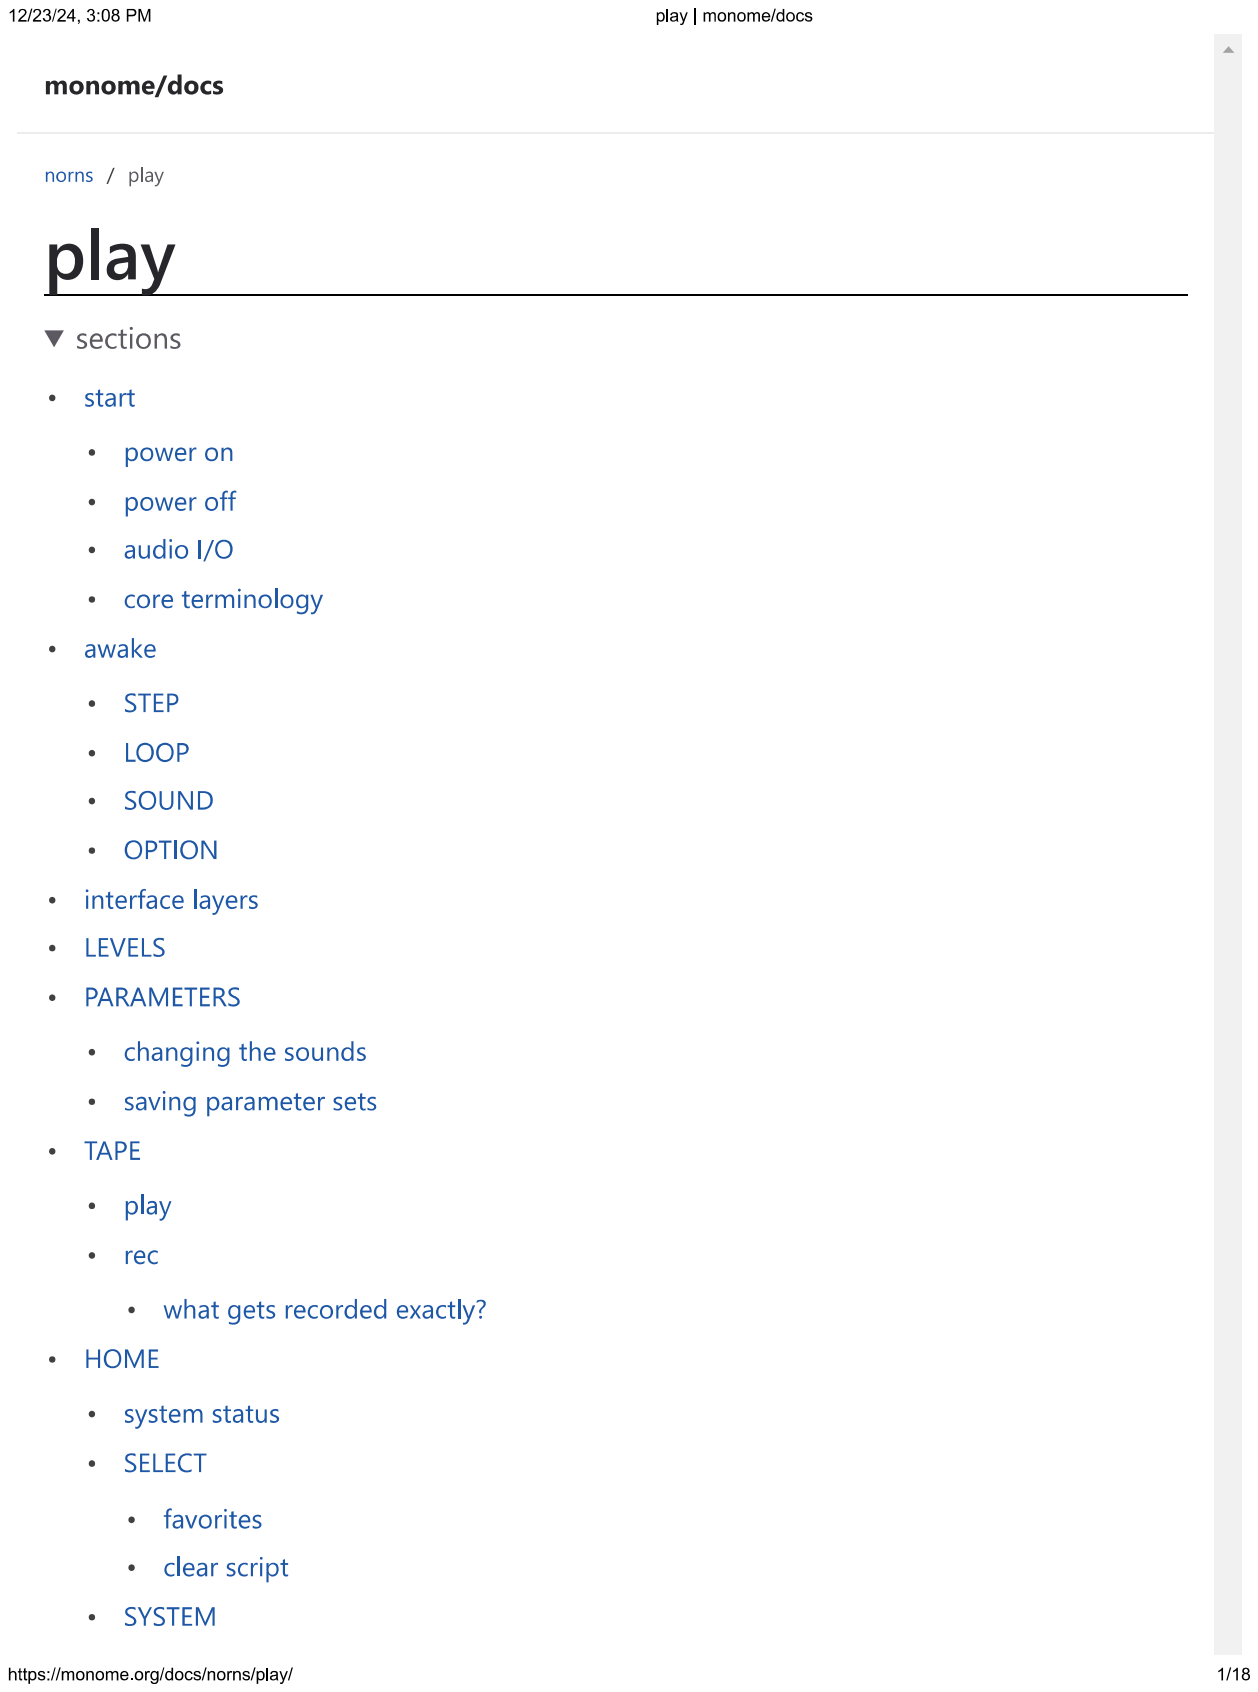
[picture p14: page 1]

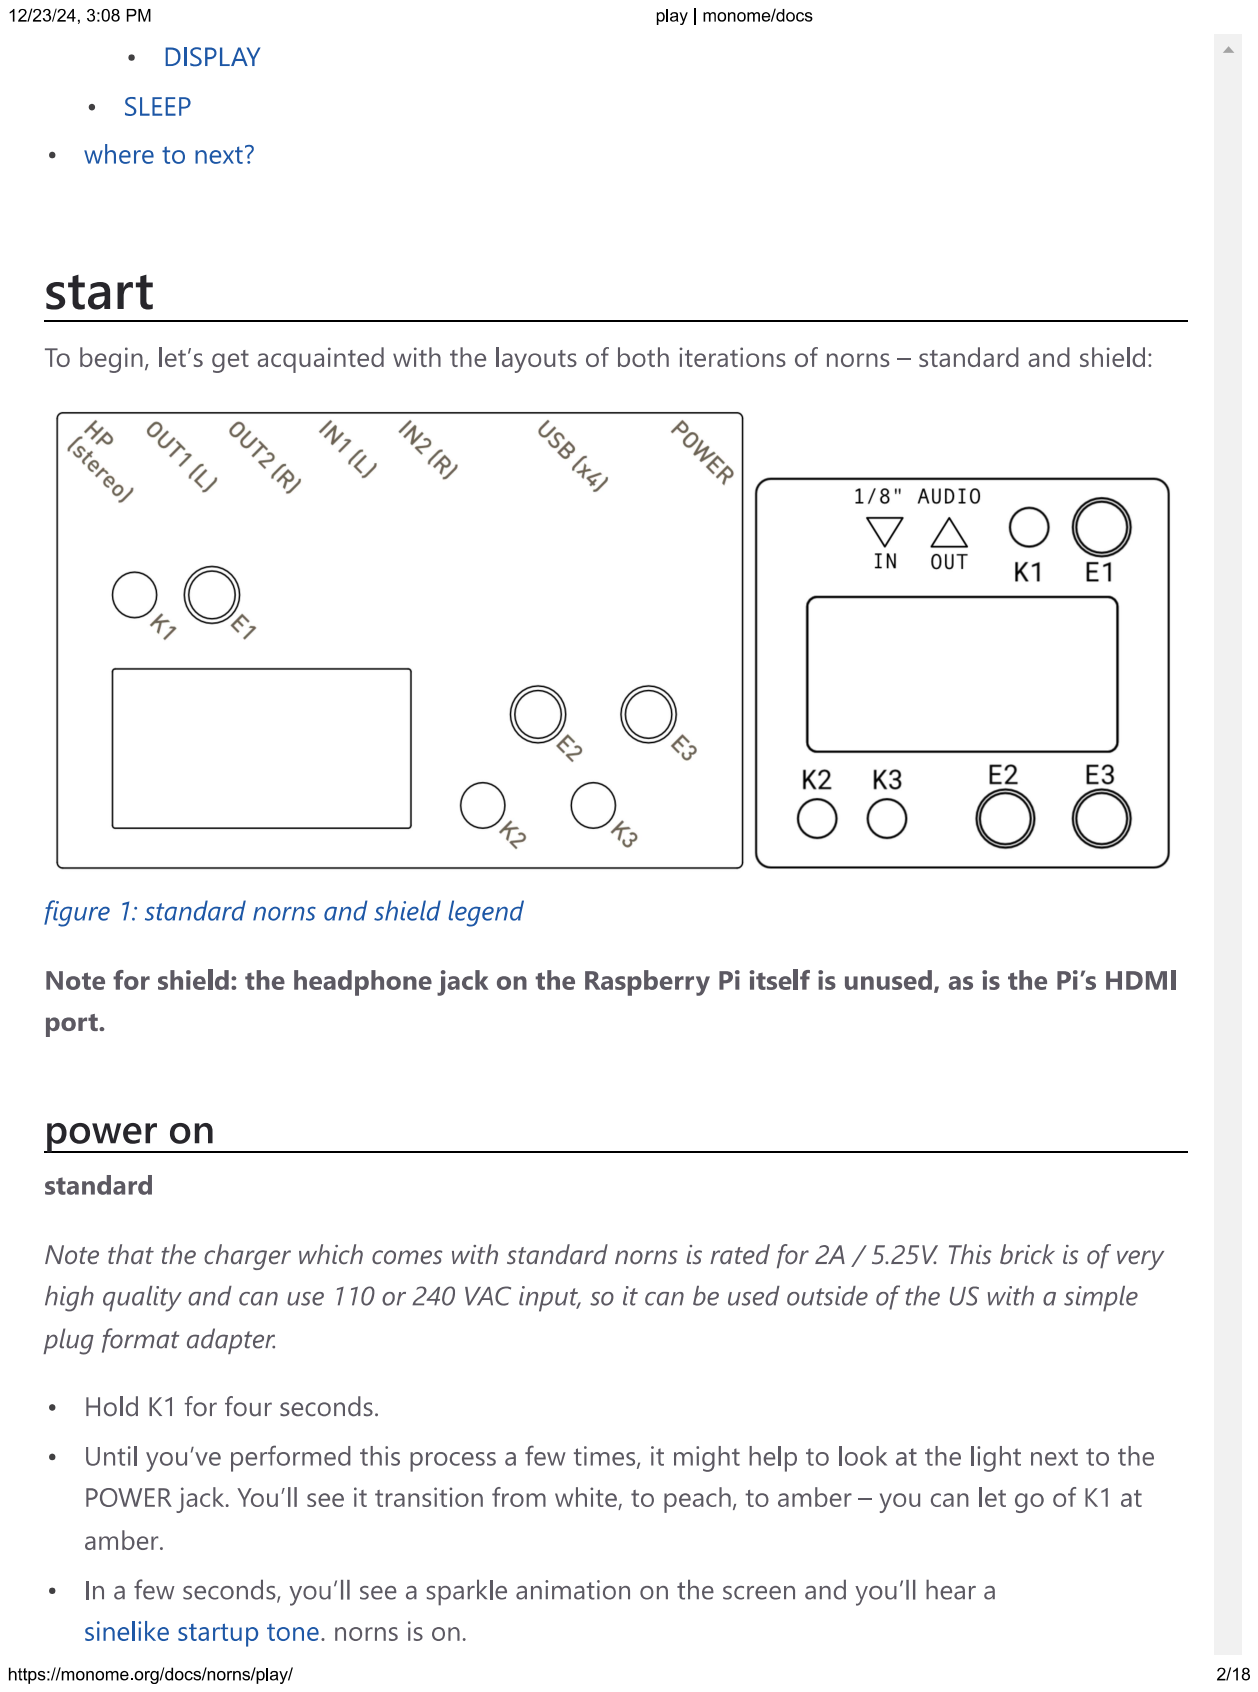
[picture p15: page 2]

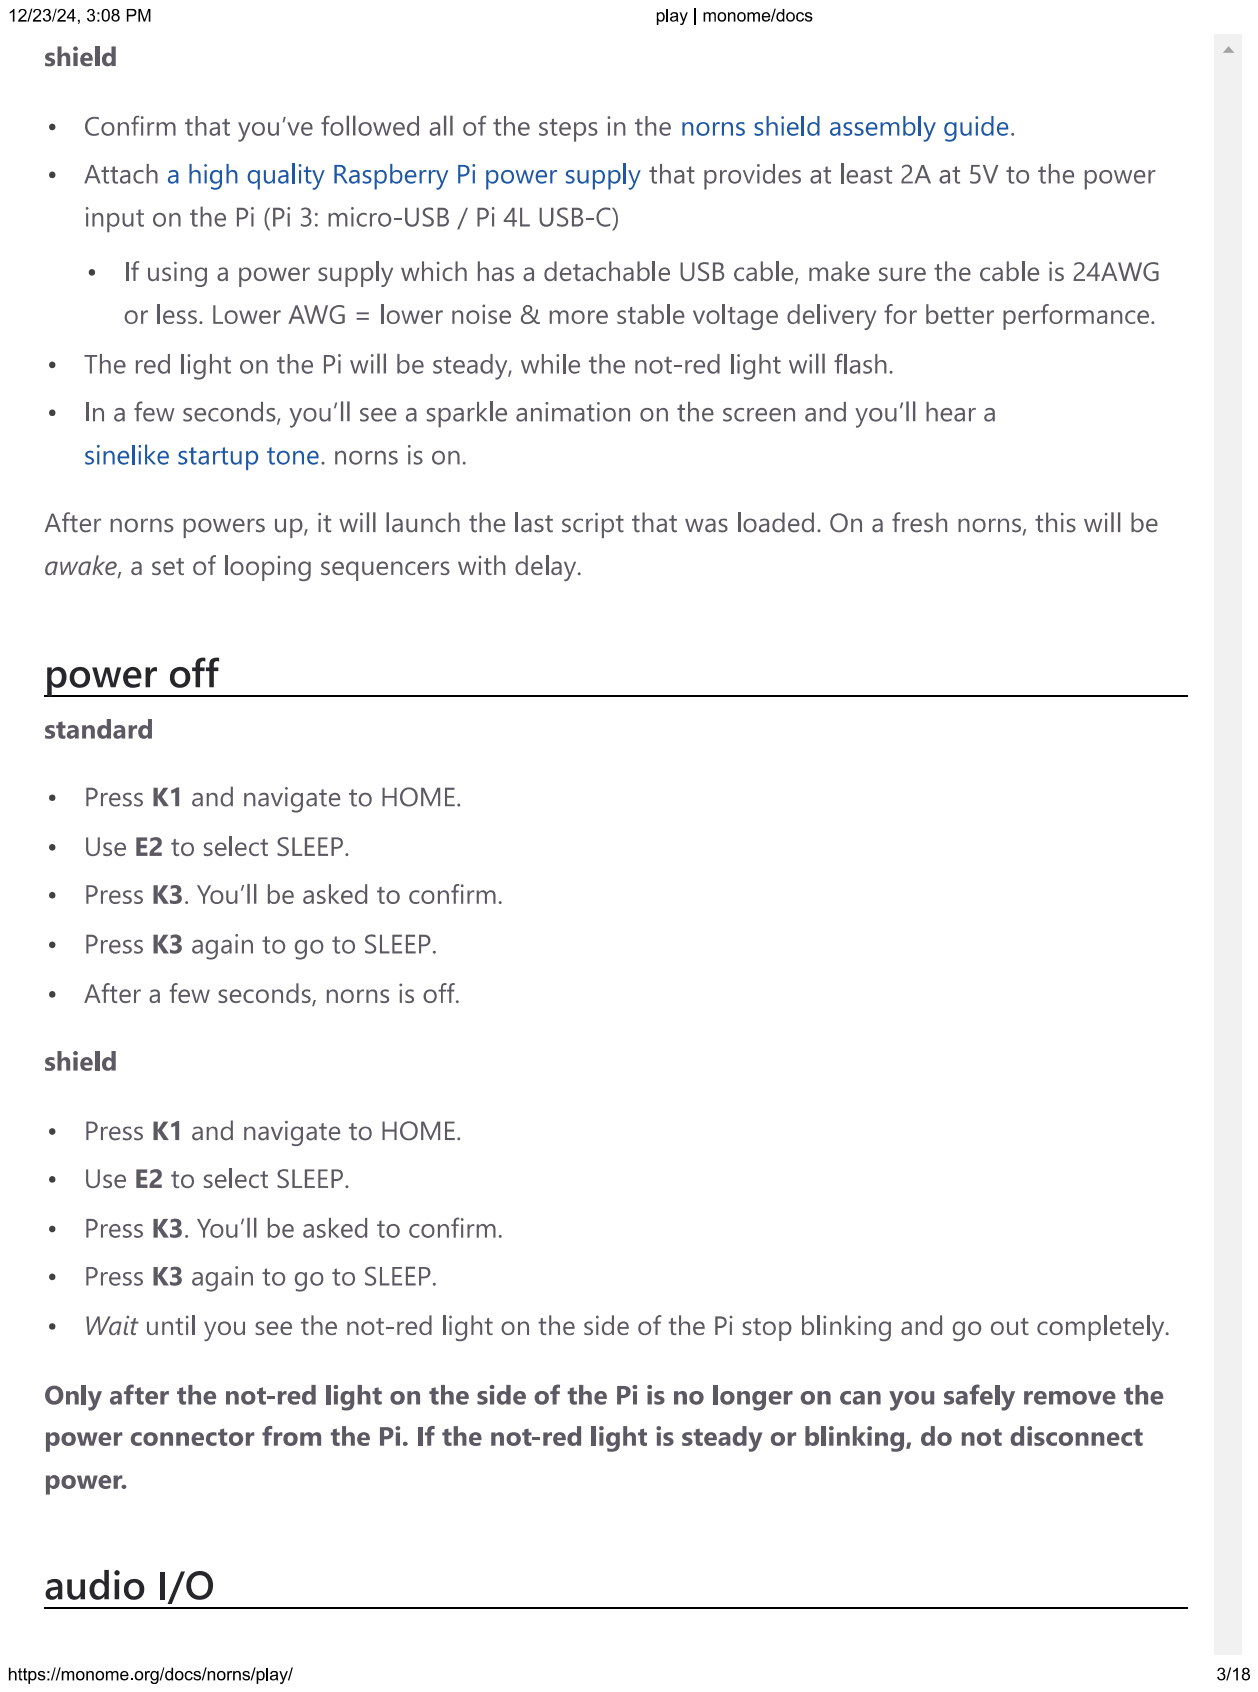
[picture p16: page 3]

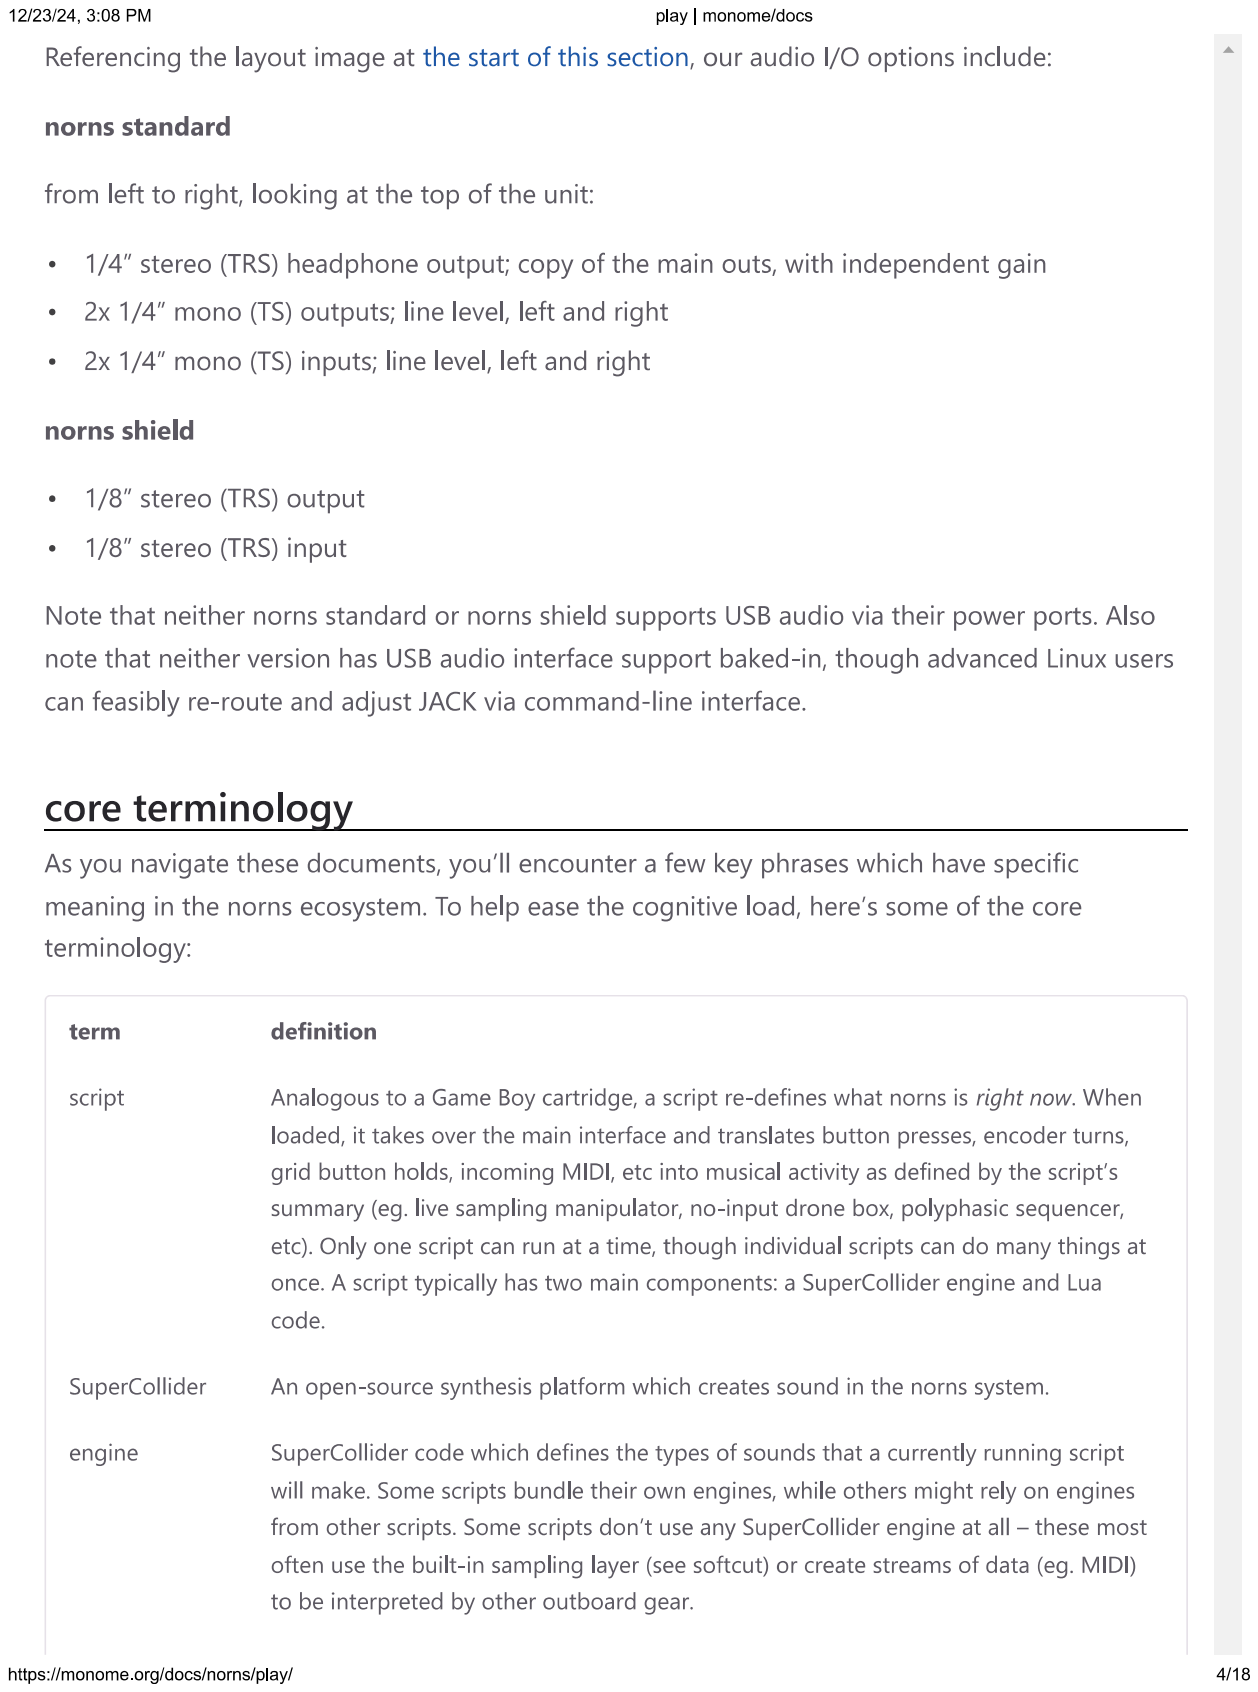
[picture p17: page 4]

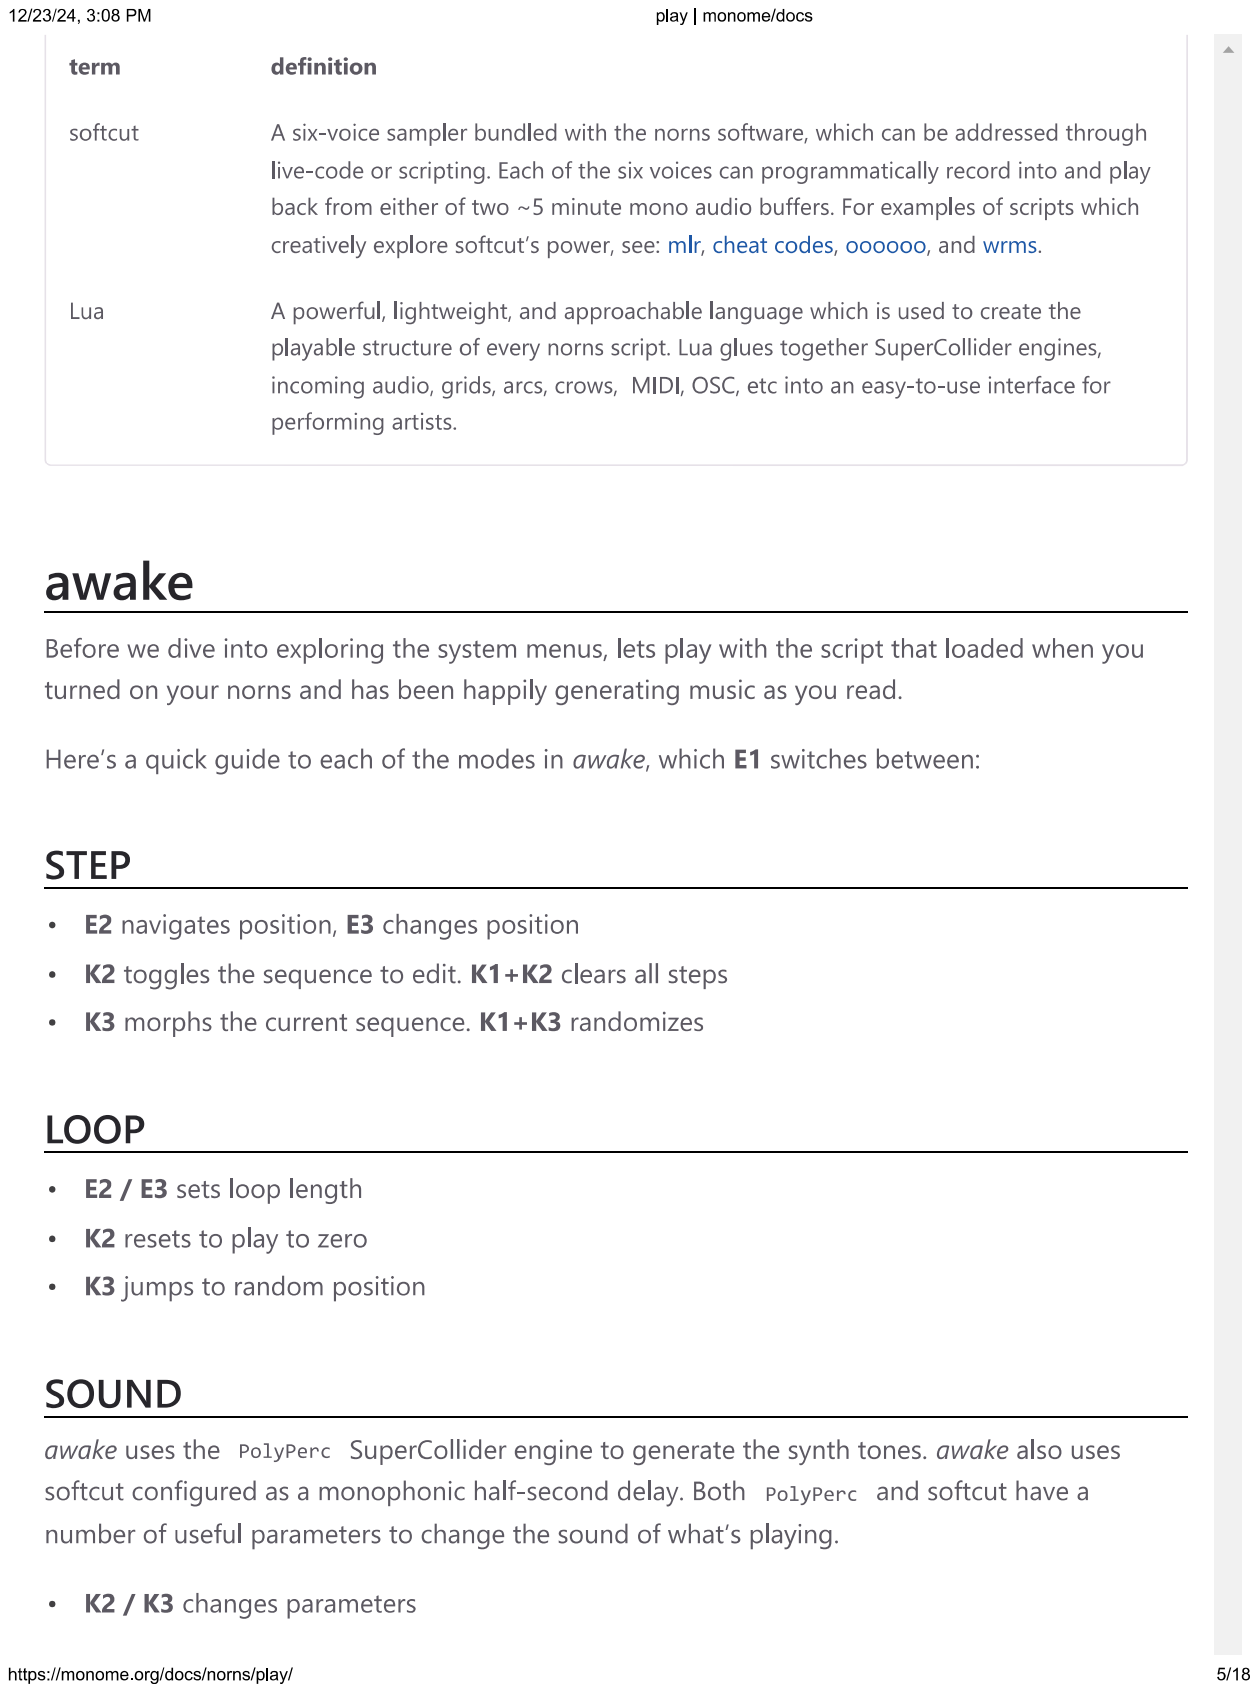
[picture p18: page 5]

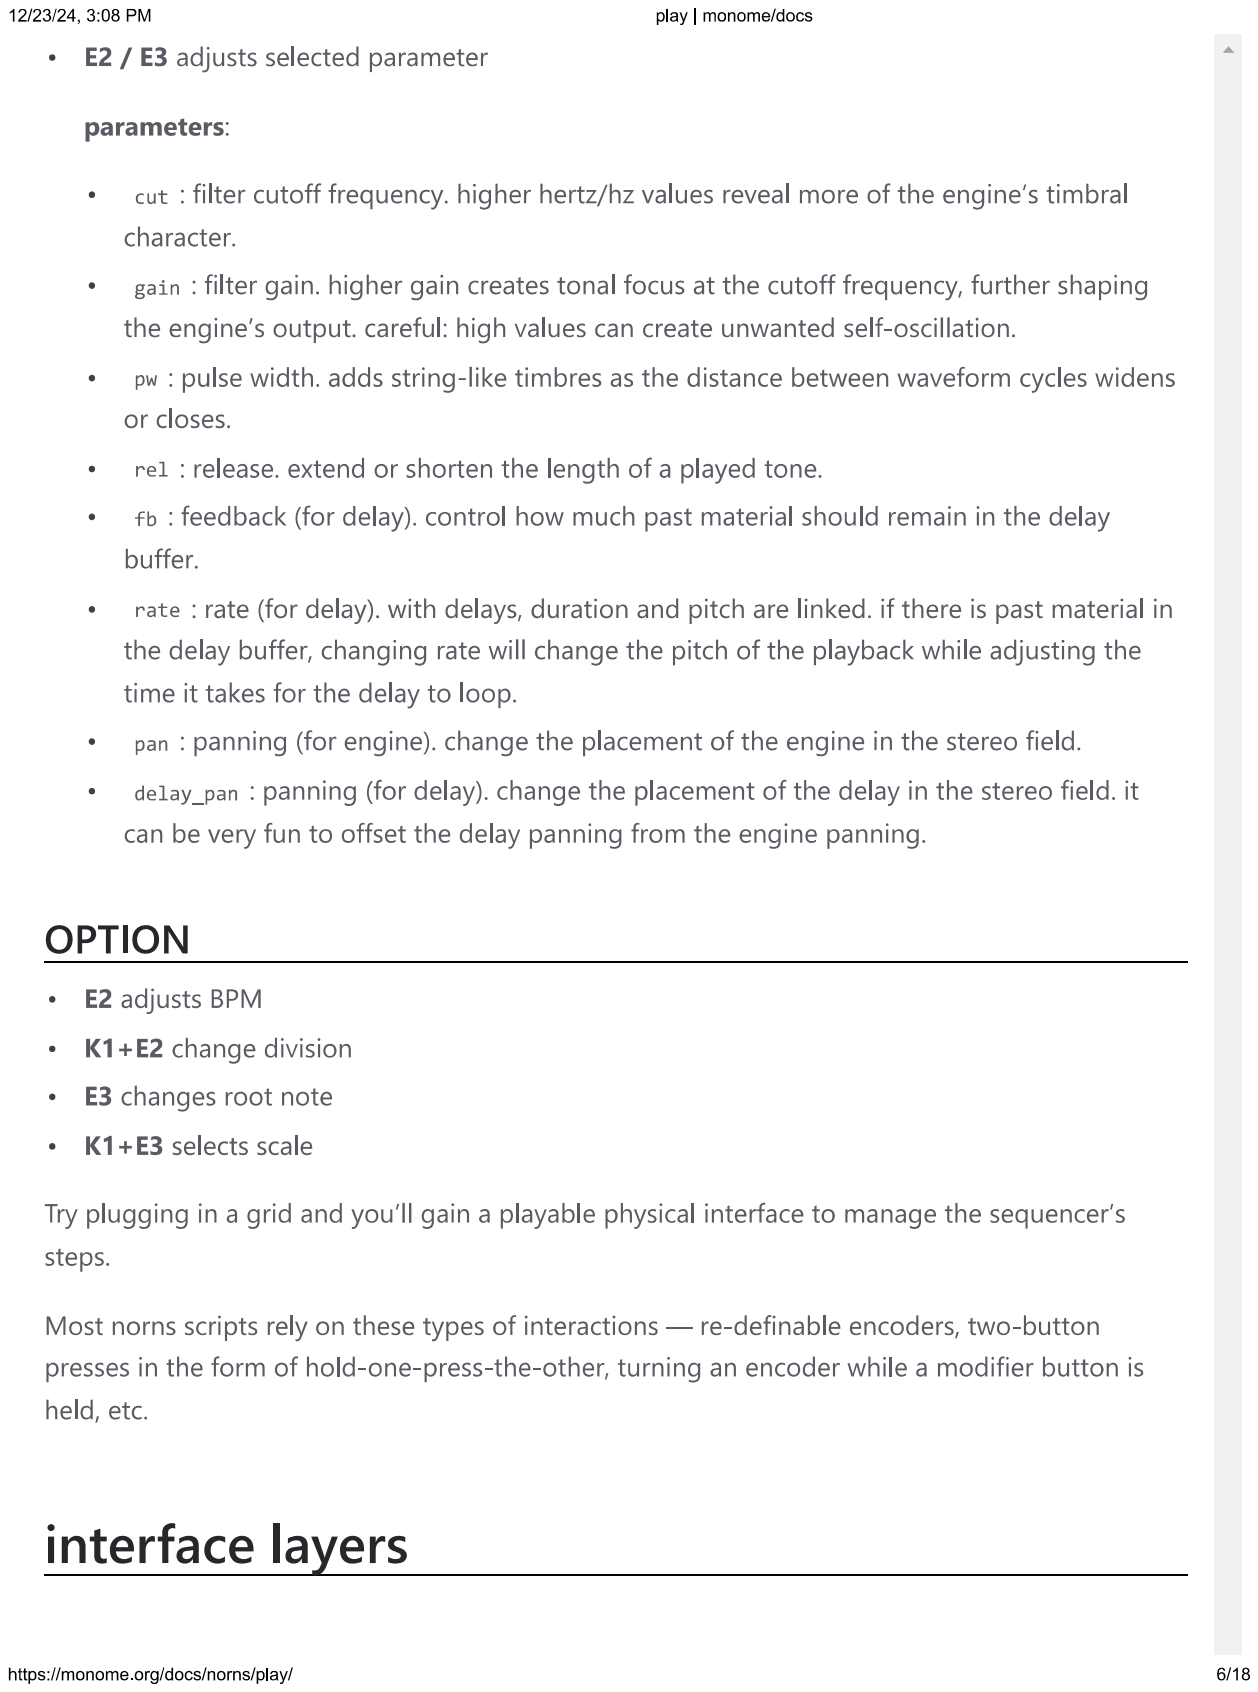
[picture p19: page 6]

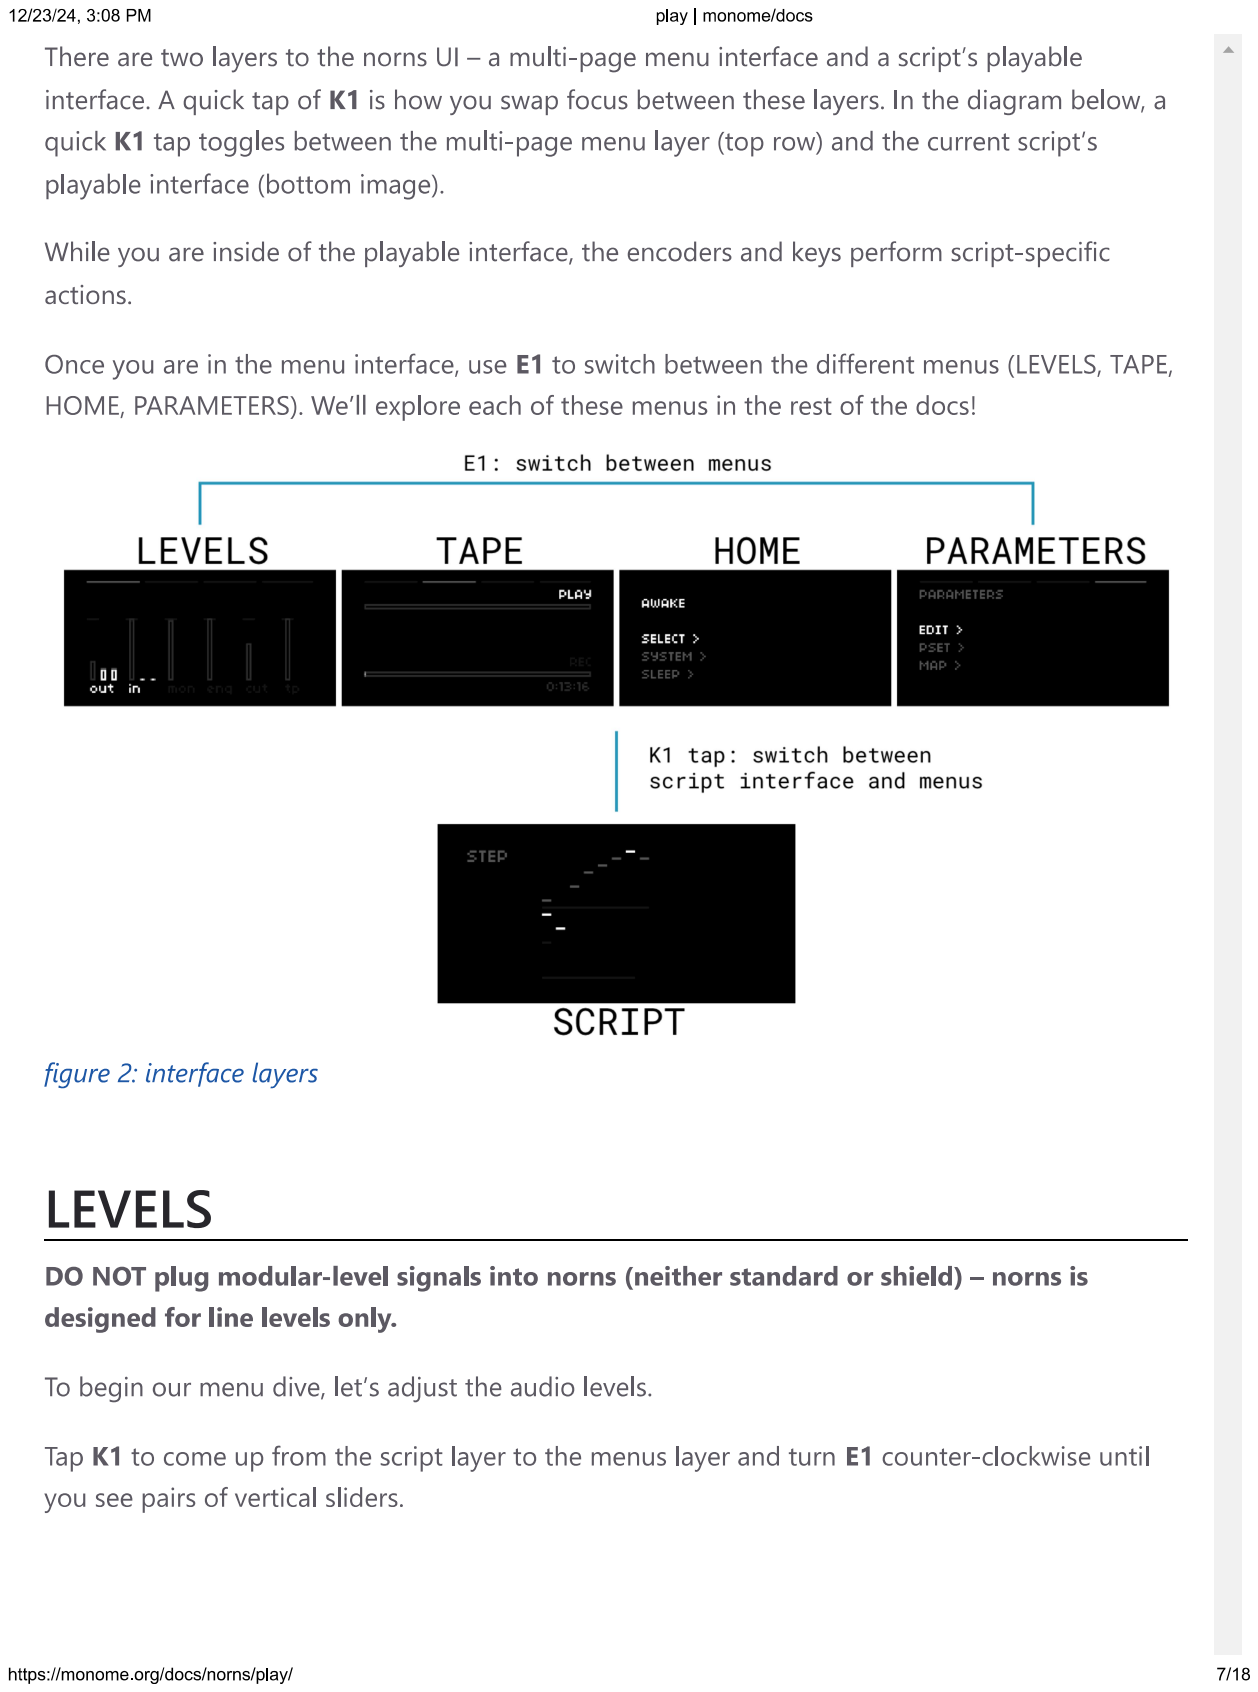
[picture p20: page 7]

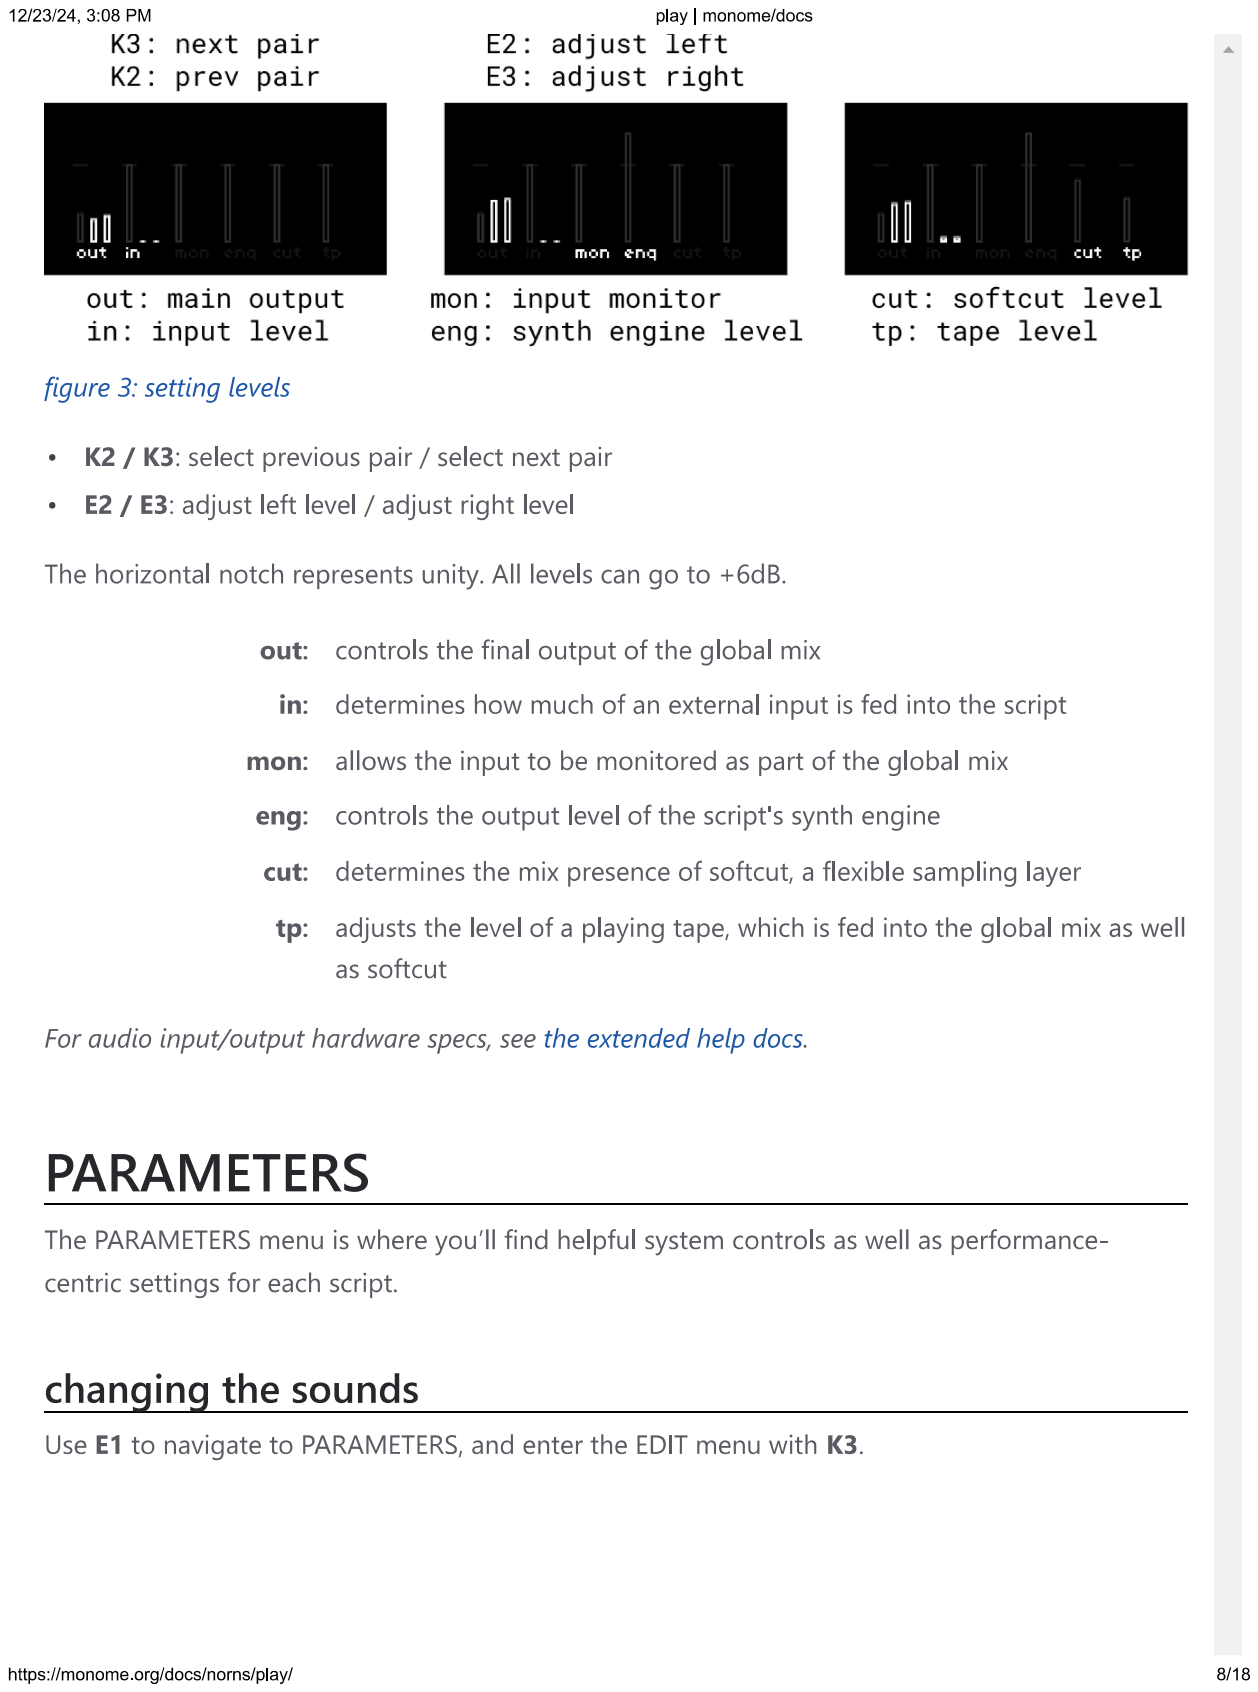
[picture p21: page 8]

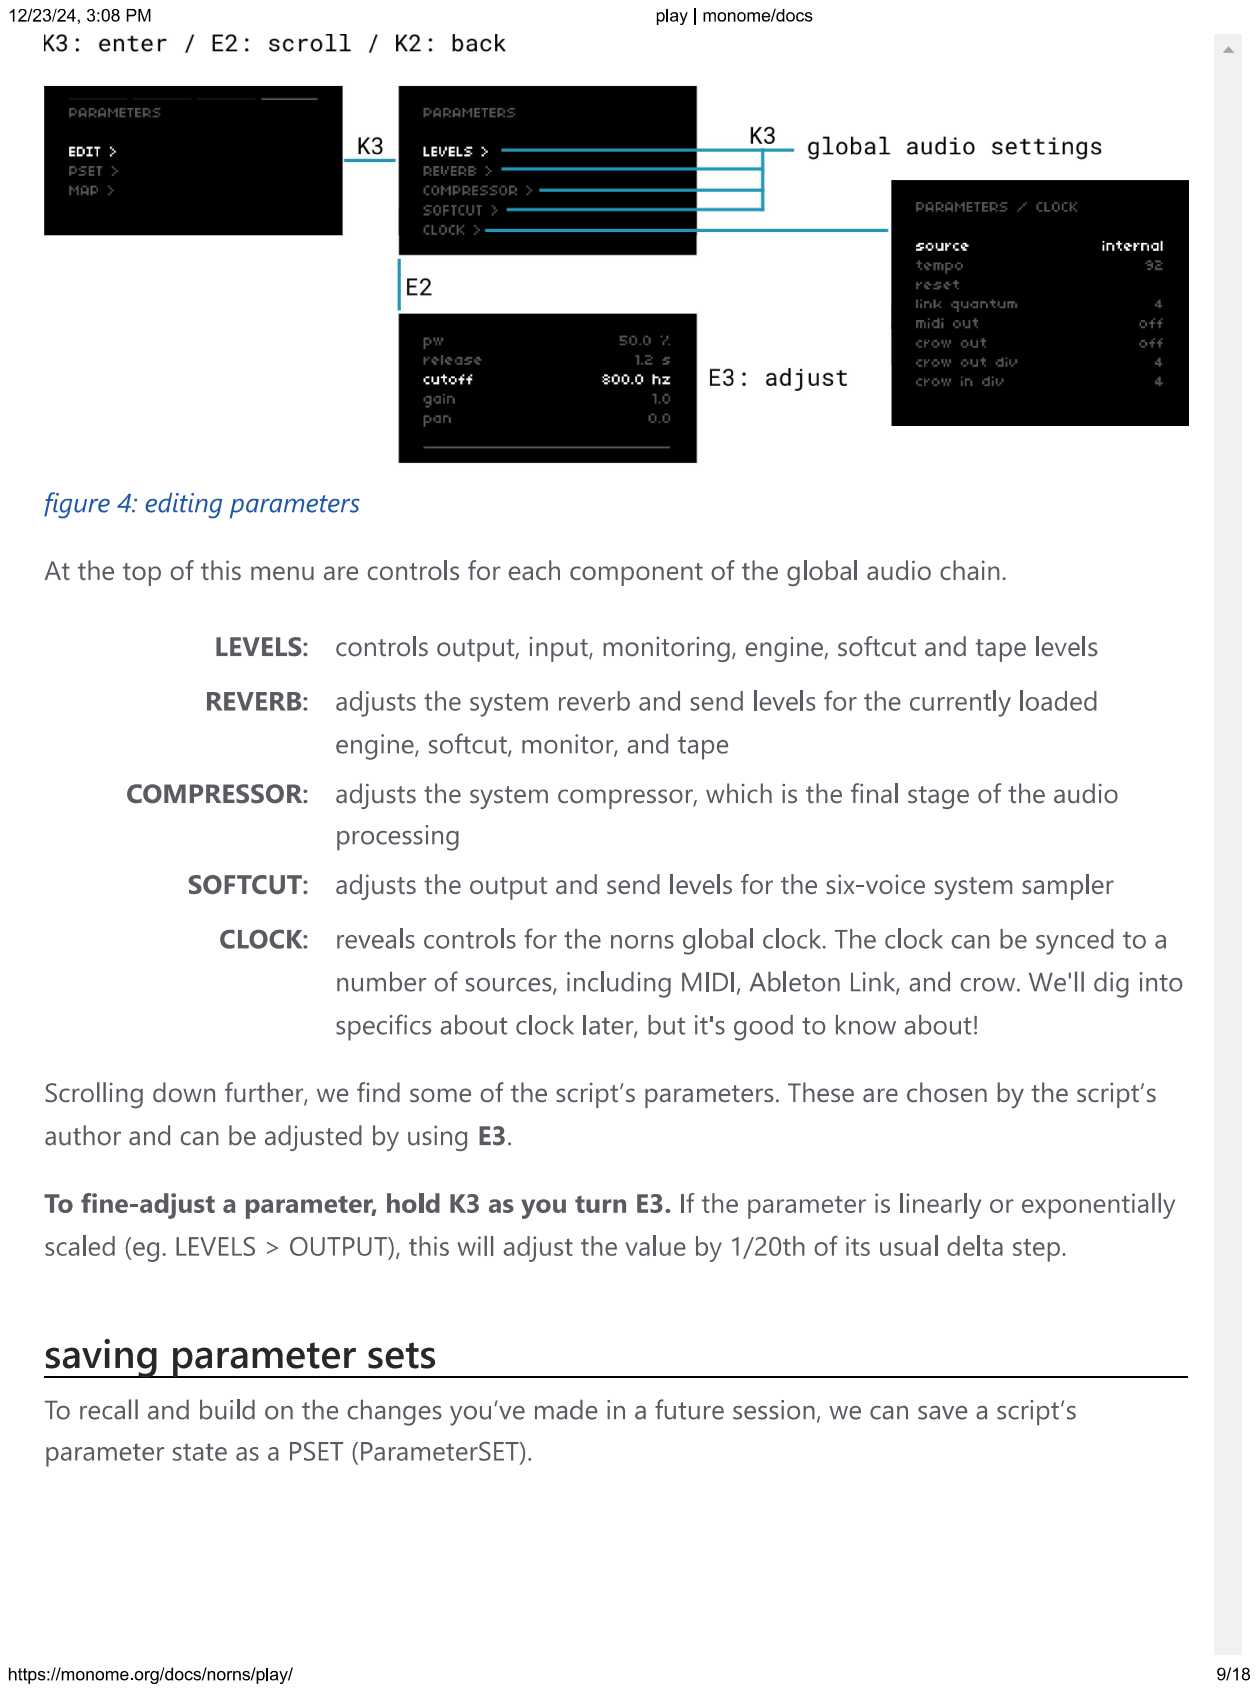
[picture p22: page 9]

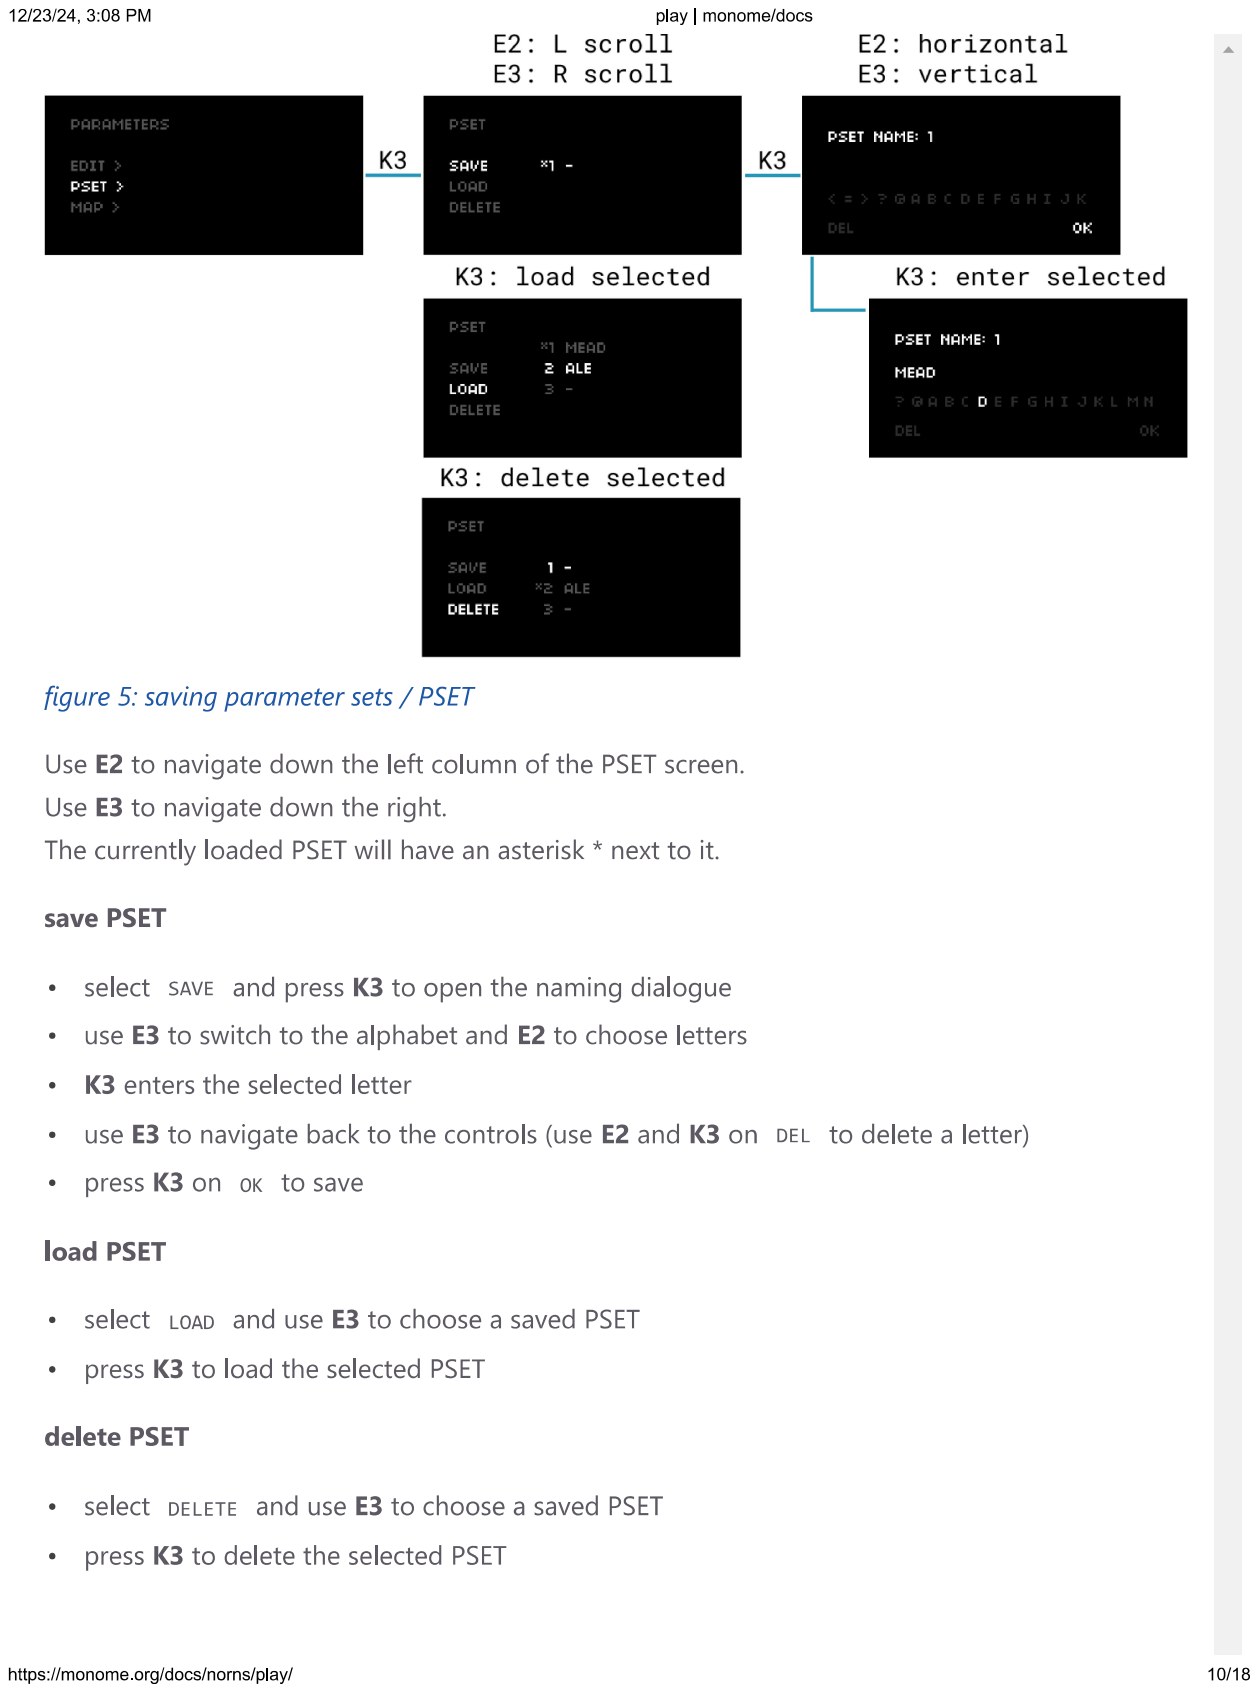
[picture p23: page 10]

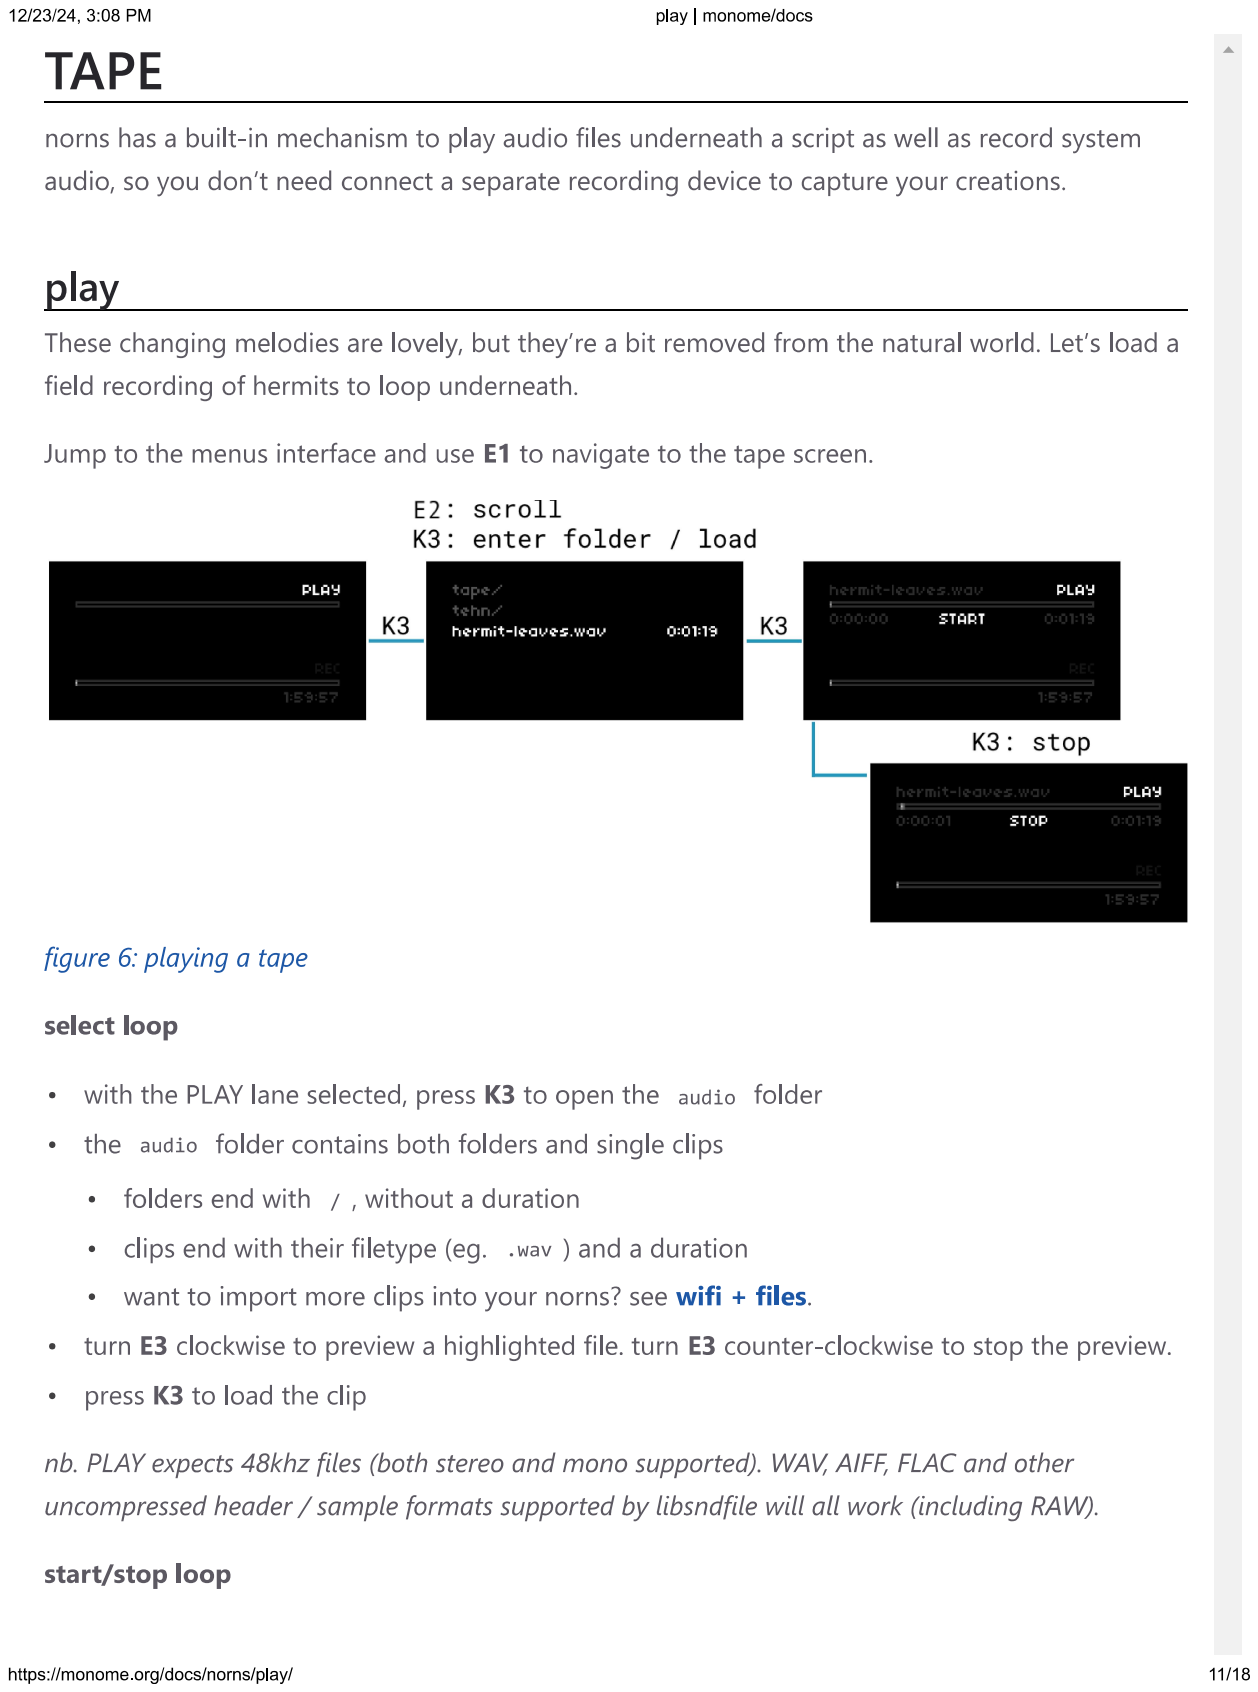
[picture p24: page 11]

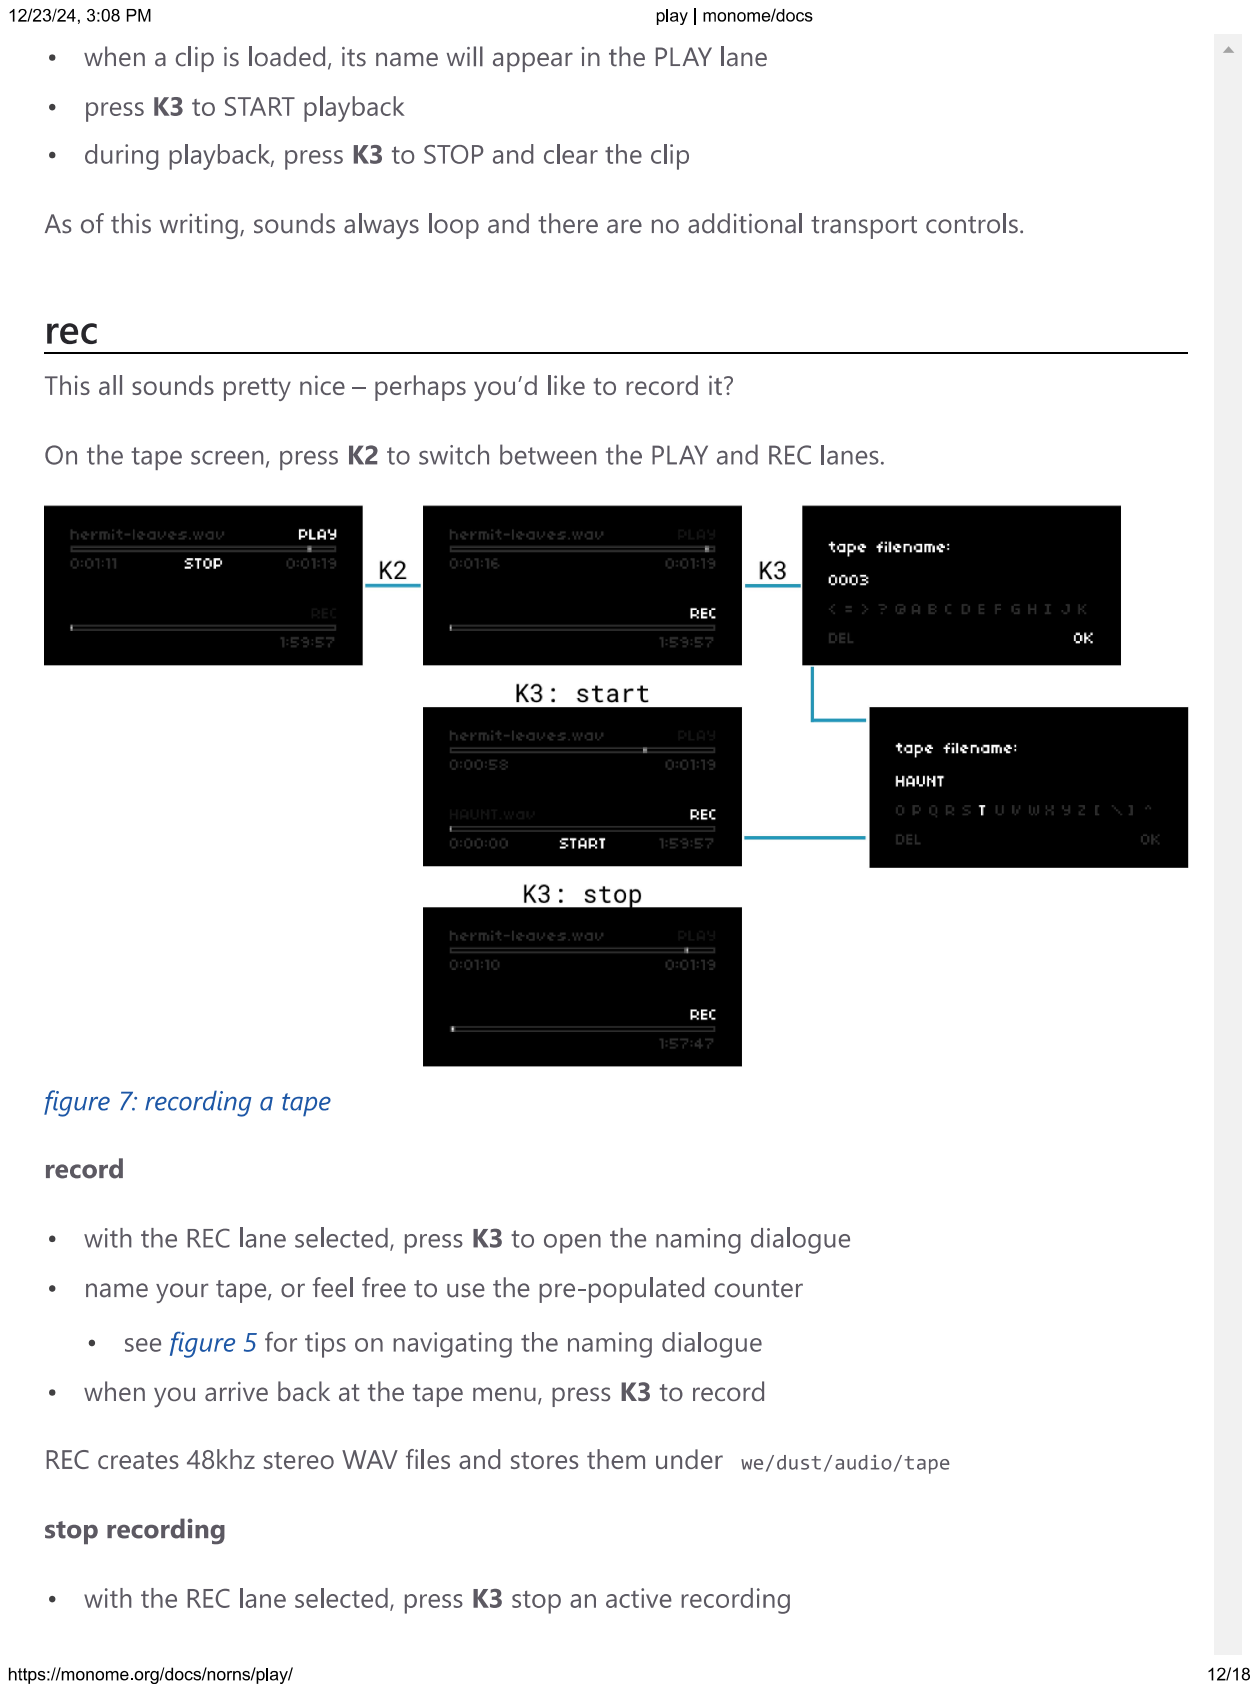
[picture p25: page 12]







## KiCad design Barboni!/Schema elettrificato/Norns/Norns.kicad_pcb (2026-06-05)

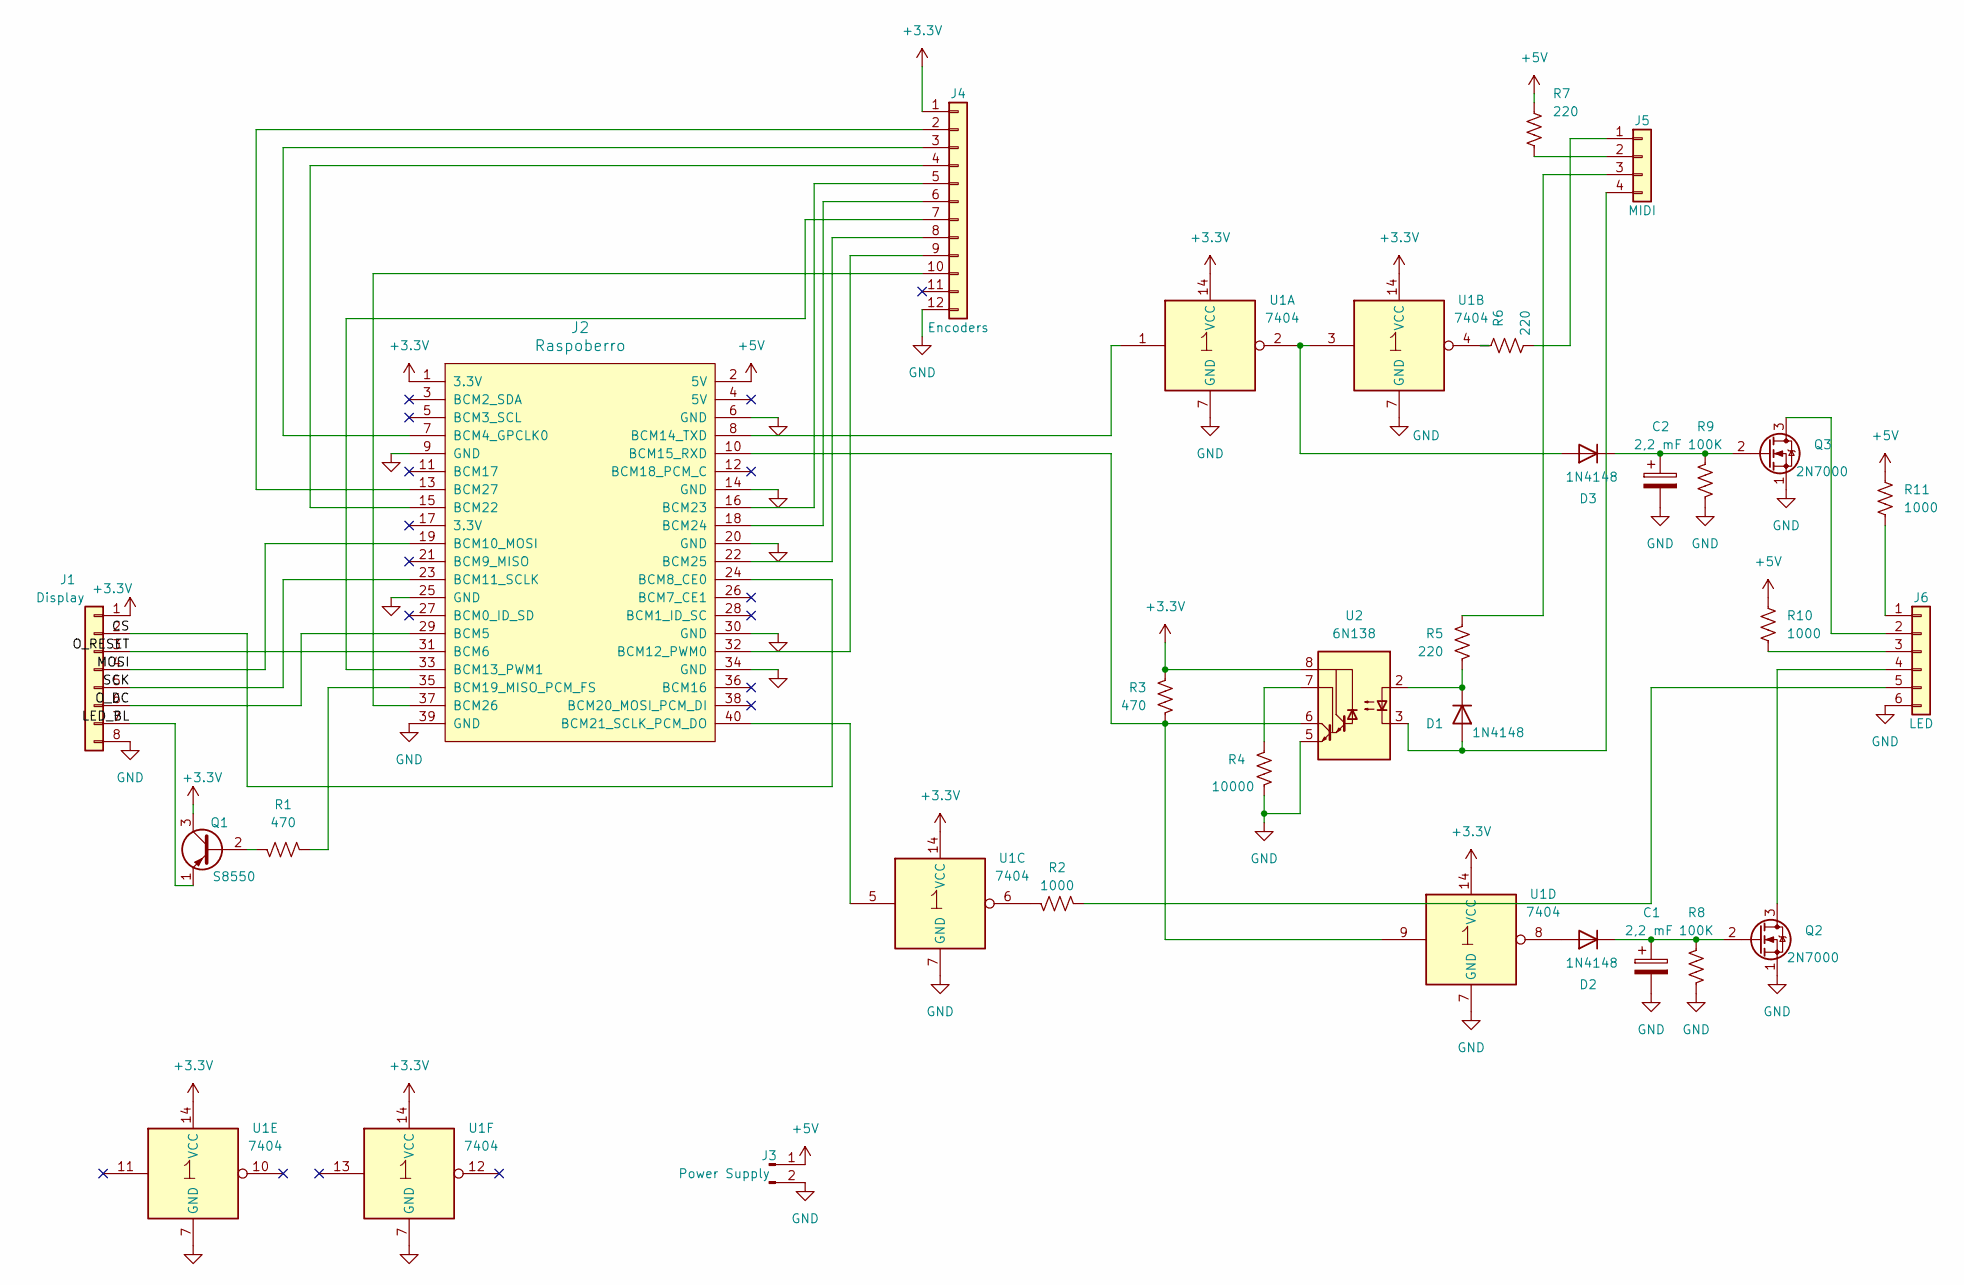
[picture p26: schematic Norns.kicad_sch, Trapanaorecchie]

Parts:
C1, C2: 2,2 mF; CP_Radial_D5.0mm_P2.50mm
D1, D2, D3: 1N4148; D_DO-35_SOD27_P7.62mm_Horizontal
J1: Display; JST_EH_B8B-EH-A_1x08_P2.50mm_Vertical
J2: Raspoberro; RPI_Hat_B+_No_Camera
J3: Power Supply; JST_EH_B2B-EH-A_1x02_P2.50mm_Vertical
J4: Encoders; JST_EH_B12B-EH-A_1x12_P2.50mm_Vertical
J5: MIDI; JST_EH_B4B-EH-A_1x04_P2.50mm_Vertical
J6: LED; JST_EH_B6B-EH-A_1x06_P2.50mm_Vertical
Q1: S8550; TO-92_Inline
Q2, Q3: 2N7000; TO-92_Inline
R1, R3: 470; R_Axial_DIN0204_L3.6mm_D1.6mm_P5.08mm_Horizontal
R2, R10, R11: 1000; R_Axial_DIN0204_L3.6mm_D1.6mm_P5.08mm_Horizontal
R4: 10000; R_Axial_DIN0204_L3.6mm_D1.6mm_P5.08mm_Horizontal
R5, R6, R7: 220; R_Axial_DIN0204_L3.6mm_D1.6mm_P5.08mm_Horizontal
R8, R9: 100K; R_Axial_DIN0204_L3.6mm_D1.6mm_P5.08mm_Horizontal
U1: 7404; DIP-14_W7.62mm
U2: 6N138; DIP-8_W7.62mm

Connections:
+3.3V: J1.1, J2.1 (3.3V), J4.1, Q1.3 (C), R3.1, U1.14 (VCC), U2.8 (VCC)
+5V: J2.2 (5V), J3.1, R7.2, R10.2, R11.2
/CS: J1.2, J2.24 (BCM8_CE0)
/LED_BL: J1.7, Q1.1 (E)
/MOSI: J1.4, J2.19 (BCM10_MOSI)
/O_DC: J1.6, J2.29 (BCM5)
/O_RESET: J1.3, J2.31 (BCM6)
/SCK: J1.5, J2.23 (BCM11_SCLK)
GND: C1.2, C2.2, J1.8, J2.6 (GND), J2.9 (GND), J2.14 (GND), J2.20 (GND), J2.25 (GND), J2.30 (GND), J2.34 (GND), J2.39 (GND), J3.2, J4.12, J6.6, Q2.1 (S), Q3.1 (S), R4.2, R8.1, R9.1, U1.7 (GND), U2.5 (GND)
unnamed: D1.2 (A), J5.4, U2.3 (C2)
unnamed: D1.1 (K), R5.1, U2.2 (C1)
unnamed: D2.2 (A), U1.8
unnamed: C1.1, D2.1 (K), Q2.2 (G), R8.2
unnamed: D3.2 (A), U1.2, U1.3
unnamed: C2.1, D3.1 (K), Q3.2 (G), R9.2
unnamed: J2.7 (BCM4_GPCLK0), J4.3
unnamed: J2.32 (BCM12_PWM0), J4.9
unnamed: J2.33 (BCM13_PWM1), J4.7
unnamed: J2.8 (BCM14_TXD), U1.1
unnamed: J2.10 (BCM15_RXD), R3.2, U1.9, U2.6 (VO2)
unnamed: J2.35 (BCM19_MISO_PCM_FS), R1.1
unnamed: J2.40 (BCM21_SCLK_PCM_DO), U1.5
unnamed: J2.15 (BCM22), J4.4
unnamed: J2.16 (BCM23), J4.5
unnamed: J2.18 (BCM24), J4.6
unnamed: J2.22 (BCM25), J4.8
unnamed: J2.37 (BCM26), J4.10
unnamed: J2.13 (BCM27), J4.2
unnamed: J5.1, R6.2
unnamed: J5.2, R7.1
unnamed: J5.3, R5.2
unnamed: J6.1, R11.1
unnamed: J6.2, Q3.3 (D)
unnamed: J6.3, R10.1
unnamed: J6.4, Q2.3 (D)
unnamed: J6.5, R2.1
unnamed: Q1.2 (B), R1.2
unnamed: R2.2, U1.6
unnamed: R6.1, U1.4
unnamed: R4.1, U2.7 (VO1)

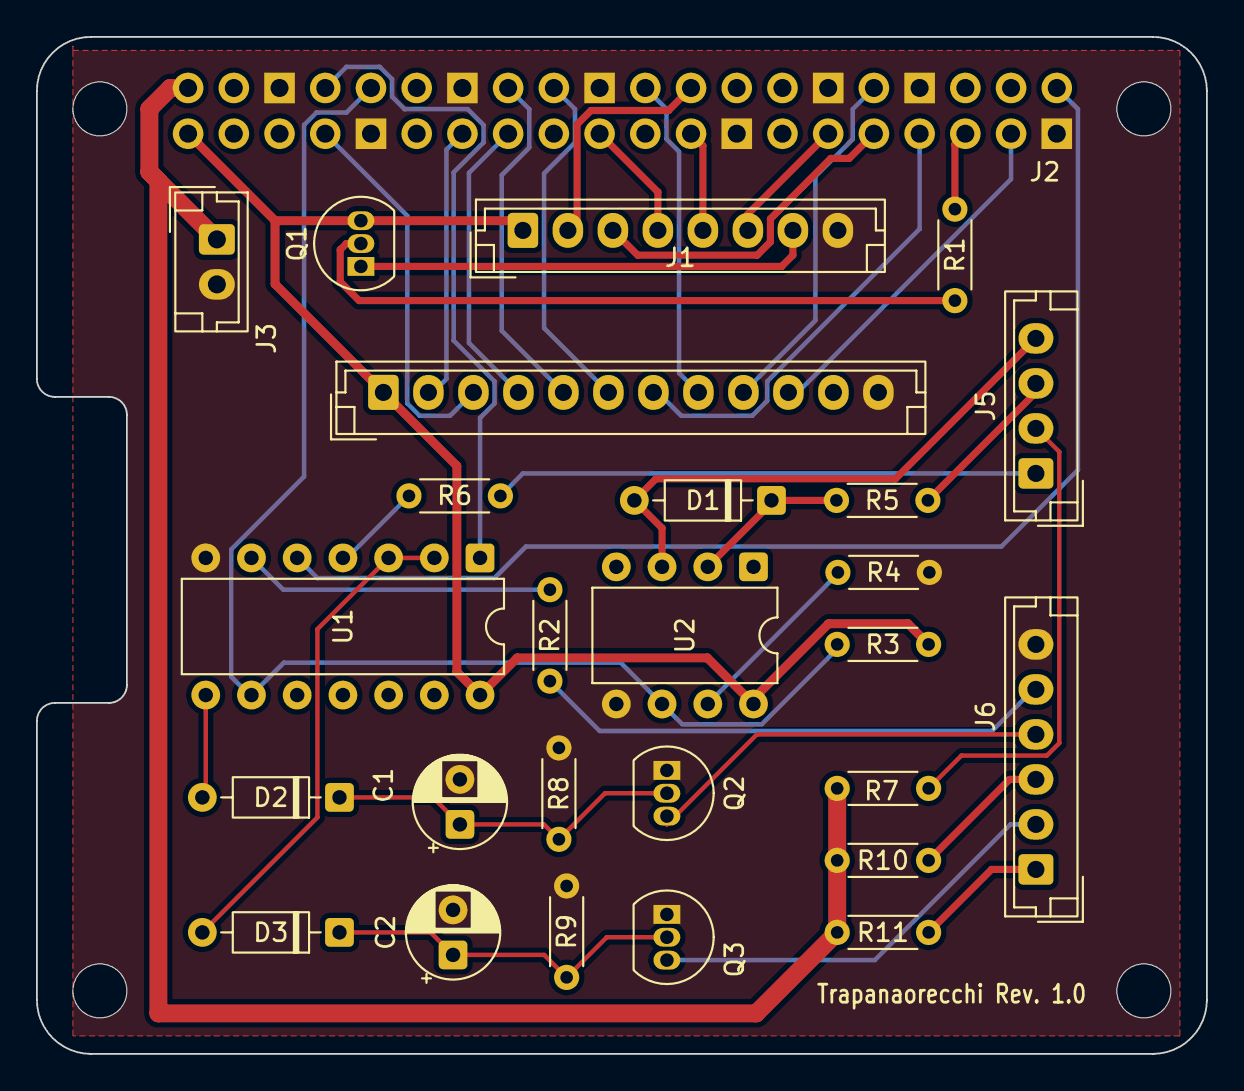
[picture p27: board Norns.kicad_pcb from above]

Board: 2 copper layers, 65.0 x 56.5 mm, 27 parts (0 on the bottom side), 40 nets.

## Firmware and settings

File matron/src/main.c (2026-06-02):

#include <pthread.h>
#include <stdbool.h>
#include <stdio.h>
#include <stdlib.h>
#include <sys/wait.h>
#include <unistd.h>

#include "args.h"
#include "battery.h"
#include "clock.h"
#include "clocks/clock_crow.h"
#include "clocks/clock_internal.h"
#include "clocks/clock_link.h"
#include "clocks/clock_midi.h"
#include "config.h"
#include "clocks/clock_scheduler.h"
#include "device.h"
#include "device_hid.h"
#include "device_list.h"
#include "device_midi.h"
#include "device_monitor.h"
#include "device_monome.h"
#include "events.h"
#include "hello.h"
#include "i2c.h"
#include "input.h"
#include "jack_client.h"
#include "metro.h"
#include "osc.h"
#include "platform.h"
#include "screen.h"
#include "screen_events.h"
#include "screen_results.h"
#include "stat.h"
#include "hardware/screen/ssd1322.h"

#include "oracle.h"
#include "weaver.h"

void print_version(void);

void cleanup(void) {
    dev_monitor_deinit();
    osc_deinit();
    o_deinit();
    w_deinit();

    config_deinit();
    i2c_deinit();
    battery_deinit();
    stat_deinit();
    jack_client_deinit();
    ssd1322_deinit();
    screen_results_deinit();
    fprintf(stderr, "matron shutdown complete\n");
    exit(0);
}

int main(int argc, char **argv) {
    args_parse(argc, argv);

    print_version();
    init_platform();
    printf("platform: %d\n",platform());

    events_init(); // <-- must come first!
    if (config_init()) {
        fprintf(stderr, "configuration failed\n");
        return -1;
    }

    metros_init();

    battery_init();
    stat_init();
    i2c_init();
    osc_init();
    jack_client_init();
    ssd1322_init();
    screen_invert(1); // ALIEXPRESS STYLE
    clock_init();
    clock_internal_init();
    clock_midi_init();
    clock_crow_init();
#if HAVE_ABLETON_LINK
    clock_link_init();
    clock_link_start();
#endif
    clock_scheduler_init();

    fprintf(stderr, "init oracle...\n");
    o_init(); // oracle (audio)

    fprintf(stderr, "init weaver...\n");
    w_init(); // weaver (scripting)

    dev_list_init();
    dev_list_add(DEV_TYPE_MIDI_VIRTUAL, NULL, "virtual");

    dev_list_add(DEV_TYPE_MIDI, "/dev/snd/midiC0D0", "laMIDI");

    fprintf(stderr, "init dev_monitor...\n");
    dev_monitor_init();

    // start listening for screen events
    screen_results_init();
    screen_events_init();

    // now is a good time to set our cleanup
    fprintf(stderr, "setting cleanup...\n");
    atexit(cleanup);

    fprintf(stderr, "init input...\n");
    // start reading input to interpreter
    input_init();

    fprintf(stderr, "running startup...\n");
    // i/o subsystems are ready; run user startup routine
    w_startup();

    // scan for connected input devices
    fprintf(stderr, "scanning devices...\n");
    dev_monitor_scan();

    // handle all resulting events, then run "post-startup"
    fprintf(stderr, "handling pending events...\n");
    event_handle_pending();

    fprintf(stderr, "running post-startup...\n");
    w_post_startup();
    
    // blocks until quit
    event_loop();
}

void print_version(void) {
    printf("MATRON\n");
    printf("norns version: %d.%d.%d\n", VERSION_MAJOR, VERSION_MINOR, VERSION_PATCH);
    printf("git hash: %s\n\n", VERSION_HASH);
}

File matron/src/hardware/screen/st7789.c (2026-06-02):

#include "ssd1322.h"

#include <string.h>

#include "events.h"
#include "event_types.h"

static int spidev_fd = 0;
static bool display_dirty = false;
static bool should_translate_color = false;
static bool should_turn_on = true;
static uint16_t * spidev_buffer = NULL;
static uint32_t * surface_buffer = NULL;
static struct gpiod_chip * gpio_0;
static struct gpiod_line * gpio_dc;
static struct gpiod_line * gpio_reset;
static struct gpiod_line * gpio_backlight;
static pthread_mutex_t lock = PTHREAD_MUTEX_INITIALIZER;
static pthread_t ssd1322_pthread_t;
static float _r_corr = 0.4797;
static float _g_corr = 0.4700;
static float _b_corr = 0.0503;
static float _bright_corr = 0.14;

#define ST7789_Portrait         0xC0
#define ST7789_Portrait180      0
#define ST7789_Landscape        0xA0
#define ST7789_Landscape180     0x60

#define SPIDEV_BUFFER_LEN      (ST7789_HEIGHT * ST7789_WIDTH * sizeof(uint16_t )) // 2 bytes per pixel
#define SURFACE_BUFFER_LEN      (ST7789_HEIGHT * ST7789_WIDTH * sizeof(uint32_t ))
#define MIN(a,b)    ((a)<(b) ? (a) : (b))

int open_spi() 
{
    int spi_fd = open(SPIDEV_0_0_PATH, O_RDWR | O_SYNC);
    if( spi_fd < 0 )
    {
        fprintf(stderr, "(screen) couldn't open %s\n", SPIDEV_0_0_PATH);
        return -1;
    }
    
 	uint8_t mode = SPI_MODE_0;
    uint8_t bits_per_word = 8;
    uint32_t speed_hz = 40000000;

    if (ioctl(spi_fd, SPI_IOC_WR_MODE, &mode) < 0 ||
        ioctl(spi_fd, SPI_IOC_WR_BITS_PER_WORD, &bits_per_word) < 0 
        || ioctl(spi_fd, SPI_IOC_WR_MAX_SPEED_HZ, &speed_hz) < 0) {
        fprintf(stderr, "could not set SPI WR settings via IOC\n");
        close(spi_fd);
        spi_fd = -1;
    }
    return spi_fd;
}

int ssd1322_write_command(uint8_t command, uint8_t data_len, ...) 
{
    va_list args;
    uint8_t cmd_buf[1];
    uint8_t data_buf[256];
    struct spi_ioc_transfer cmd_transfer = {0};
    struct spi_ioc_transfer data_transfer = {0};

    pthread_mutex_lock(&lock);

    if( spidev_fd <= 0 ){
        fprintf(stderr, "%s: spidev not yet opened\n", __func__);
        goto fail;
    }

    gpiod_line_set_value(gpio_dc, 0);

    cmd_buf[0] = command;
    cmd_transfer.tx_buf = (unsigned long) cmd_buf;
    cmd_transfer.len = (uint32_t) sizeof(cmd_buf);

    if( ioctl(spidev_fd, SPI_IOC_MESSAGE(1), &cmd_transfer) < 0 ){
        fprintf(stderr, "%s: could not send command-message.\n", __func__);
        goto fail;
    }

    if( data_len > 0 ){
        gpiod_line_set_value(gpio_dc, 1);

        va_start(args, data_len);

        for( uint8_t i = 0; i < data_len; i++ ){
            data_buf[i] = va_arg(args, int);
        }

        va_end(args);

        data_transfer.tx_buf = (unsigned long) data_buf;
        data_transfer.len = (uint32_t) data_len;

        if( ioctl(spidev_fd, SPI_IOC_MESSAGE(1), &data_transfer) < 0 ){
            fprintf(stderr, "%s: could not send data-message.\n", __func__);
            goto fail;
        }
    }

    pthread_mutex_unlock(&lock);
    return 0;
    fail:
    pthread_mutex_unlock(&lock);
    return -1;
}

int write_data(uint8_t data) 
{
    struct spi_ioc_transfer data_transfer = {0};
    uint8_t data_buf[1];

    pthread_mutex_lock(&lock);

    if (spidev_fd <= 0) {
        fprintf(stderr, "%s: spidev not yet opened\n", __func__);
        pthread_mutex_unlock(&lock);
        return -1;
    }

    gpiod_line_set_value(gpio_dc, 1);

    data_buf[0] = data;
    data_transfer.tx_buf = (unsigned long) data_buf;
    data_transfer.len = (uint32_t) sizeof(data_buf);

    if (ioctl(spidev_fd, SPI_IOC_MESSAGE(1), &data_transfer) < 0) {
        fprintf(stderr, "%s: could not send data-message.\n", __func__);
        pthread_mutex_unlock(&lock);
        return -1;
    }

    pthread_mutex_unlock(&lock);
    return 0;
}

#ifndef NUMARGS
#define NUMARGS(...)  (sizeof((int[]){__VA_ARGS__}) / sizeof(int))
#endif
#define write_command_with_data(x, ...) (ssd1322_write_command(x, NUMARGS(__VA_ARGS__), __VA_ARGS__))
#define write_command(x) (ssd1322_write_command(x, 0, 0))

static void* ssd1322_thread_run(void * p) 
{
    (void)p;

    static struct timespec ts = 
	{
        .tv_sec = 0,
        .tv_nsec = 16666666, // 60Hz
    };

    while( spidev_buffer )
	{
        if( display_dirty )
		{
            ssd1322_refresh();
            display_dirty = false;
        }

        // If this event happens right before ssd1322_refresh(),
        // there is quite a bit of flashing. Possibly from being
        // at a weird sync point with the hardware refresh.
        event_post(event_data_new(EVENT_SCREEN_REFRESH));

        clock_nanosleep(CLOCK_MONOTONIC, 0, &ts, NULL);
    }

    return NULL;
}

void ssd1322_init() 
{
    if( pthread_mutex_init(&lock, NULL) != 0 ){
        fprintf(stderr, "%s: pthread_mutex_init failed\n", __func__);
        return;
    }

    surface_buffer = calloc(SURFACE_BUFFER_LEN, 1);
    if( surface_buffer == NULL ){
        fprintf(stderr, "%s: couldn't allocate surface_buffer\n", __func__);
        return;
    }

    spidev_buffer = calloc(SPIDEV_BUFFER_LEN, 1);
    if( spidev_buffer == NULL ){
        fprintf(stderr, "%s: couldn't allocate spidev_buffer\n", __func__);
        return;
    }

    spidev_fd = open_spi();
    if( spidev_fd < 0 )
	{
        fprintf(stderr, "%s: couldn't open %s.\n", __func__, SPIDEV_0_0_PATH);
        return;
    }

    gpio_0 = gpiod_chip_open_by_name(SSD1322_DC_AND_RESET_GPIO_CHIP);
    gpio_dc = gpiod_chip_get_line(gpio_0, SSD1322_DC_GPIO_LINE);
    gpio_reset = gpiod_chip_get_line(gpio_0, SSD1322_RESET_GPIO_LINE);
    gpio_backlight = gpiod_chip_get_line(gpio_0, 19);

    // nomi ottenibili col comando gpioinfo
    gpiod_line_request_output(gpio_dc, "D/C", 0);
    gpiod_line_request_output(gpio_reset, "RST", 0);
    gpiod_line_request_output(gpio_backlight, "GPIO19", 1);

    // Reset the display
    gpiod_line_set_value(gpio_reset, 1);
    usleep(100000); // 100 ms
    gpiod_line_set_value(gpio_reset, 0);
    usleep(100000); // 100 ms
    gpiod_line_set_value(gpio_reset, 1);
    usleep(100000); // 100 ms
    gpiod_line_set_value(gpio_backlight, 0); // accende il display
  
    // Initialization sequence
    write_command(0x11);
    usleep(500000); 

    // MADCTL parameters (page 212)
    // Bits 0-1: Unused
    // Bit 2: 0=LCD refresh left-to-right, 1=right-to-left
    // Bit 3: 0=RGB mode, 1=BGR mode

    // Bit 4: 0=LCD refresh top-to-bottom, 1=bottom-to-top
    // Bit 5: Page/column order. 0=normal mode, 1=reverse mode
    // Bit 6: Column address order. 0=left-to-right, 1=right-to-left
    // Bit 7: Page address order. 0=top-to-bottom, 1=bottom-to-top
    // write_command_with_data(0x36, 0x08 | ST7789_Landscape180);// Rotate the screen by 270 degrees (versione BGR)
    write_command_with_data(0x36,  ST7789_Landscape180);// Rotate the screen by 270 degrees

	// RGB 16-bit color mode
    write_command_with_data(0x3a, 0x55);
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

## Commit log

2021-07-10 il norns dei barboni
2024-12-16 Enhance screen rendering by applying device scaling to surfaces
2024-12-20 cul de sac
2024-12-31 millostonno #1
2024-12-31 millostonno #2
2024-12-31 power off mngmnt
2024-12-31 la perfezione dei barboni
2025-01-18 lcd a 3.3V
2025-03-16 grande zia assunta!
    [schema elettrico.kicad_sch]
2025-04-02 potenziometro antilogaritmico
    [pote.kicad_sch]
2025-04-03 potenzometro antilog
    [pote.kicad_sch]
2025-05-15 update, non ci siamo ancora
    [midi_led.kicad_sch, potenziometro antilog.kicad_sch, schema elettrico.kicad_sch]
2026-01-13 la si avanza
    [Norns.kicad_pcb, Norns.kicad_sch, pote.kicad_sch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]
2026-01-18 avanzamento di progressione
    [Norns.kicad_pcb, Norns.kicad_sch, Rialzo led-Corpo.3mf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]
2026-01-19 schema el
    [Norns.kicad_pcb, Norns.kicad_sch]
2026-01-22 scatola inf terminata
    [Norns.FCStd]
2026-01-22 quas fernut
    [Norns.FCStd]
2026-01-22 scatola base ok
    [Norns.FCStd]
2026-01-22 scatola terminata
    [Norns.FCStd]
2026-01-22 rimosse vecchie code
    [misurazioni misuranti-3 led.3mf, misurazioni misuranti-Deviatore.3mf, misurazioni misuranti-Pulsanti.3mf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]
2026-01-29 altra iterasiun
    [Norns.FCStd]
2026-01-31 test 2
    [Norns-Lo Scatolo.3mf, Norns-Pannello frontaliero.3mf, Norns.FCStd]
